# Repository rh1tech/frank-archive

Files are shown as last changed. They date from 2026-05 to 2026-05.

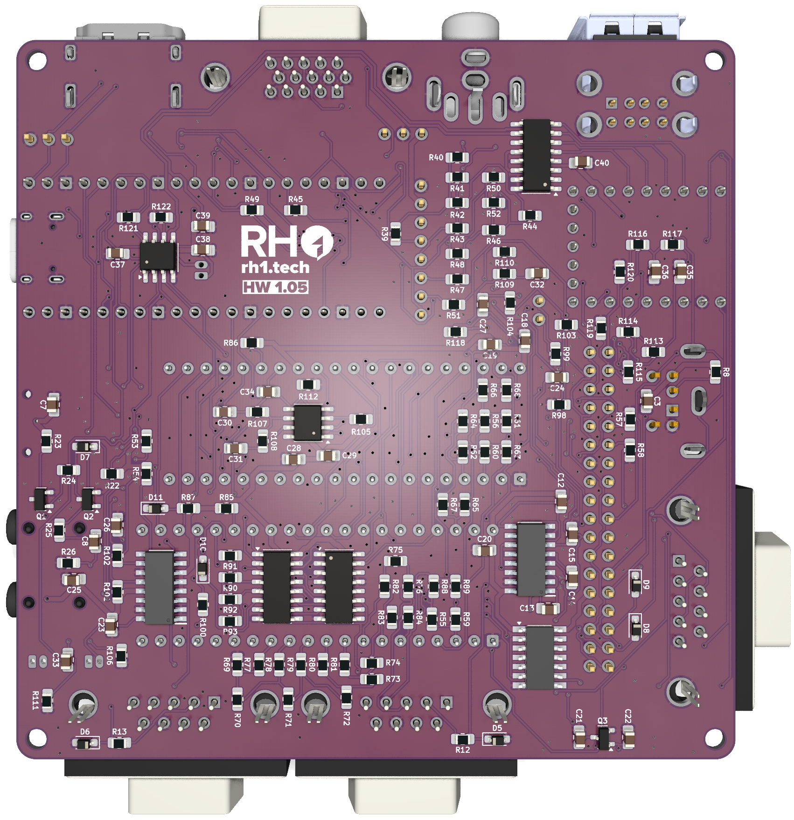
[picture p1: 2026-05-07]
turbofrank_m1p1/docs/back.png

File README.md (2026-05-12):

# FRANK Archive

Official page: **[frank.rh1.tech](https://frank.rh1.tech/)** — hub for all FRANK boards and firmware.

Archive of FRANK board revisions — schematics, layouts, and reference assets for each released and prototyped variant of the FRANK family.

Each subdirectory corresponds to a specific board revision, including the FRANK, MicroFRANK, MiniFRANK, TinyFRANK, TurboFRANK, and related accessory boards (HDMI-to-VGA, USB-to-PS/2).

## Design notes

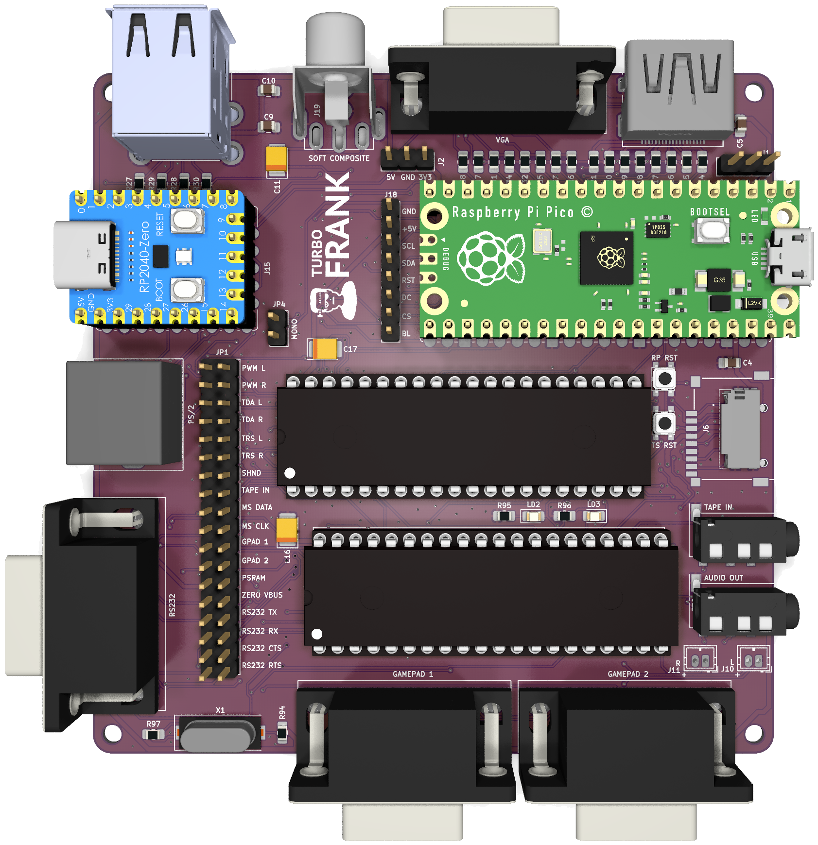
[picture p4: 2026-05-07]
turbofrank_m1p1/docs/front.png

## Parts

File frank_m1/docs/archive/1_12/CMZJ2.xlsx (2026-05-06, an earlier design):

Reference | Value | Qty | Type | AliExpress
AU1 | AUDIO OUT | 1 | PJ-325C | https://www.aliexpress.com/item/1005006710837751.html
AU2 | AUDIO IN | 1 | PJ-325C | https://www.aliexpress.com/item/1005006710837751.html
C1,C2,C3,C6 | 1u | 4 | Polar | https://www.aliexpress.com/item/1005002524973878.html
C4,C7,C8,C14,C5,C13 | 100n | 6 | SMD | https://www.aliexpress.com/item/32964553793.html
C9,C10,C15 | 10u | 3 | 0805 | https://www.aliexpress.com/item/32964553793.html
C11,C12 | 10n | 2 | 0805 | https://www.aliexpress.com/item/32964553793.html
C16 | 220u | 1 | Polar | https://www.aliexpress.com/item/1005002524973878.html
CON1 | Display | 1 | 2.54 | https://www.aliexpress.com/item/1005007039504981.html
CON2 | OUT | 1 | 2.54 | https://www.aliexpress.com/item/1005007039504981.html
CON3 | IN | 1 | 2.54 | https://www.aliexpress.com/item/1005007039504981.html
D1,D2,D3 | 1N4148 | 3 | SOD-323 | https://www.aliexpress.com/item/1005007681952673.html
D4,D5,D6,D7,PWR2 | 3V3 | 5 | SOD-323 | https://www.aliexpress.com/item/32997486634.html
DB1 | RS232 | 1 | DB9 Female | https://www.aliexpress.com/item/4000659356343.html
DB2,DB3 | Joystick | 2 | DB9 Female | https://www.aliexpress.com/item/4000659356343.html
HDMI1 | HDMI | 1 | Female 4 DIP | https://www.aliexpress.com/item/1005005248842433.html
JP1 | JMP RUN | 1 | 2.54 | https://www.aliexpress.com/item/1005007039504981.html
JP2 | Main Jumpers | 1 | 2.54 | https://www.aliexpress.com/item/1005007039504981.html
JP3 | GP18 Jumper | 1 | 2.54 | https://www.aliexpress.com/item/1005007039504981.html
JP4 | GP19 Jumper | 1 | 2.54 | https://www.aliexpress.com/item/1005007039504981.html
JP5 | JMP PSRAM | 1 | 2.54 | https://www.aliexpress.com/item/1005007039504981.html
JP6 | RS232 Jumpers | 1 | 2.54 | https://www.aliexpress.com/item/1005007039504981.html
JP7,JP9,JP10 | RP ZERO +5V Jumper | 3 | 2.54 | https://www.aliexpress.com/item/1005007039504981.html
JP8 | I2S | 1 | 2.54 | https://www.aliexpress.com/item/1005007039504981.html
KB1 | PS/2 | 1 | PS/2 6P | https://www.aliexpress.com/item/4000106131593.html
L1 | LED | 1 | 0805 | https://www.aliexpress.com/item/838002118.html
MAX1 | MAX232CSE+ | 1 | SO 16PIN | https://www.aliexpress.com/item/1005006286473801.html
PSR1 | PSRAM | 1 | SOP8 | https://www.aliexpress.com/item/1005006440914173.html
PWR1 | 5V | 1 | 2.54 | https://www.aliexpress.com/item/1005007039504981.html
Q1,Q2 | BC850 | 2 | SOT-23 | https://www.aliexpress.com/item/33017911878.html
R1,R2,R11,R35,R36,R37,R38,R55 | 1K | 8 | 0805 | https://www.aliexpress.com/item/1005005600798857.html
R3,R4,R5,R6,R7,R8,R9,R10,R40,R41,R42,R43,R44,R45 | 270R | 14 | 0805 | https://www.aliexpress.com/item/1005005600798857.html
R12,R13,R14,R25,R26 | 330R | 5 | 0805 | https://www.aliexpress.com/item/1005005600798857.html
R15,R16,R17,R30,R33 | 1k | 5 | 0805 | https://www.aliexpress.com/item/1005005600798857.html
R18,R19,R20,R21,R27,R28,R29,R34 | 10K | 8 | 0805 | https://www.aliexpress.com/item/1005005600798857.html
R22,R23,R24,R47,R48 | 100R | 5 | 0805 | https://www.aliexpress.com/item/1005005600798857.html
R31,R32 | 2k | 2 | 0805 | https://www.aliexpress.com/item/1005005600798857.html
R39 | 750R | 1 | 0805 | https://www.aliexpress.com/item/1005005600798857.html
R46 | 300R | 1 | 0805 | https://www.aliexpress.com/item/1005005600798857.html
R49,R50,R51,R52,R53 | 150R | 5 | 0805 | https://www.aliexpress.com/item/1005005600798857.html
R54 | 51R | 1 | 0805 | https://www.aliexpress.com/item/1005005600798857.html
R56,R57 | 5.1K | 2 | 0805 | https://www.aliexpress.com/item/1005005600798857.html
RP1 | RP2040 Pico | 1 | Pico | https://www.aliexpress.com/item/1005006055009344.html
RP2 | RP 2040 Zero | 1 | Zero | https://www.aliexpress.com/item/1005006354505058.html
SC1 | VIDEO (Soft Composite) | 1 | RCA-103 | https://www.aliexpress.com/item/1005006152724809.html
SD1 | Micro SD | 1 | Push-Push | https://www.aliexpress.com/item/1005004214252441.html
SW1 | SW_Push_Dual | 1 | 3 x 3 x 1.5 mm | https://www.aliexpress.com/item/1005001629293584.html
TDA1 | TDA1387T | 1 | SOP-8 | https://www.aliexpress.com/item/32995595000.html
UART1 | UART | 1 | 2.54 | https://www.aliexpress.com/item/1005007039504981.html
USB1 | USB Type C | 1 | 16 Pin SMT | https://www.aliexpress.com/item/1005005500797563.html
VGA1 | VGA | 1 | DB15 Female 90 Degree | https://www.aliexpress.com/item/32842951548.html

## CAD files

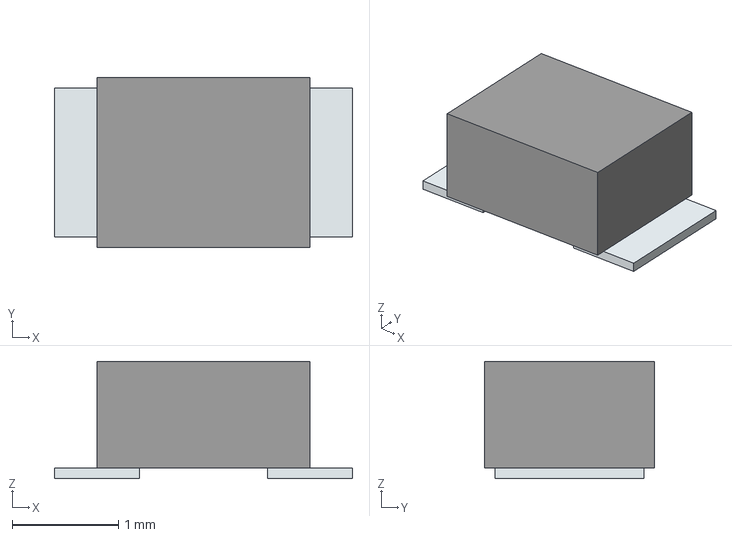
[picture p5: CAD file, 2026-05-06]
microfrank_rm1p2u/3D/ASMPH-0806-3R3M-T.stp
2.80 x 1.60 x 1.10 mm
Pins

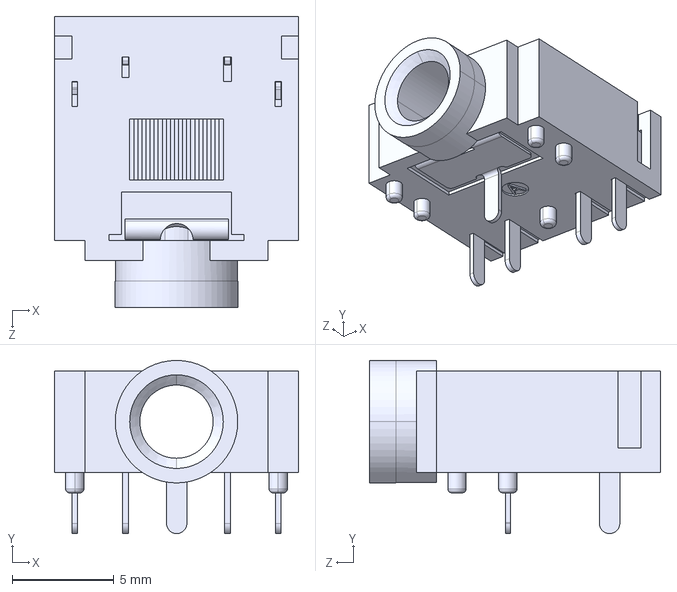
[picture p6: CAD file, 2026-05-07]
frank_fastbeta_m1/3d/SJ1-3525N.stp
12.0 x 8.51 x 14.3 mm

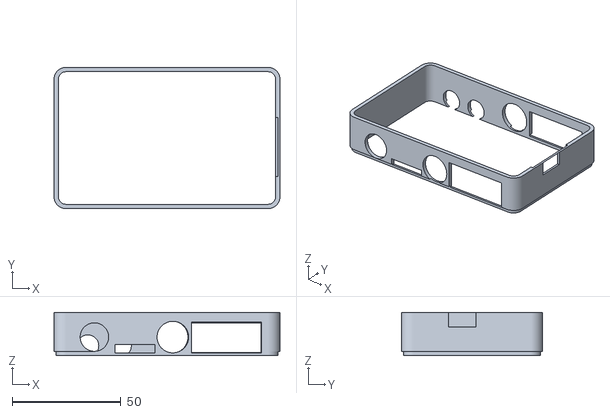
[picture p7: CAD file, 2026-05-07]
frank_fastbeta_m1/case/1_04/body_vga.stl
104.0 x 65.0 x 20.0

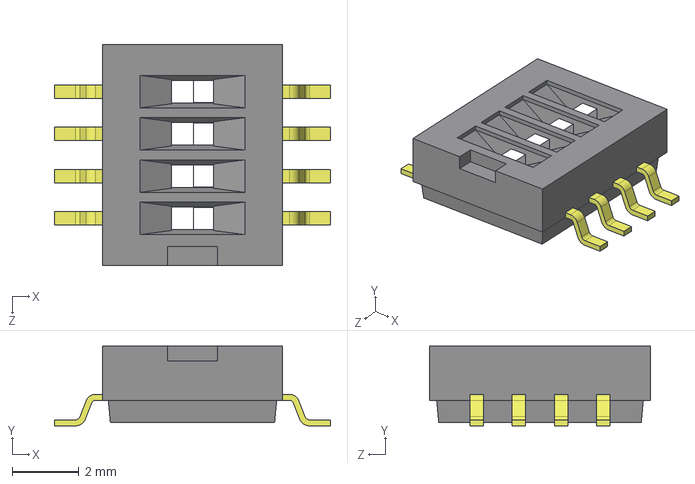
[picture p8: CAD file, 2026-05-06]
frank_m1/3d/DS05-127-2-04BK-SMT-TR.step
8.30 x 2.40 x 6.65 mm

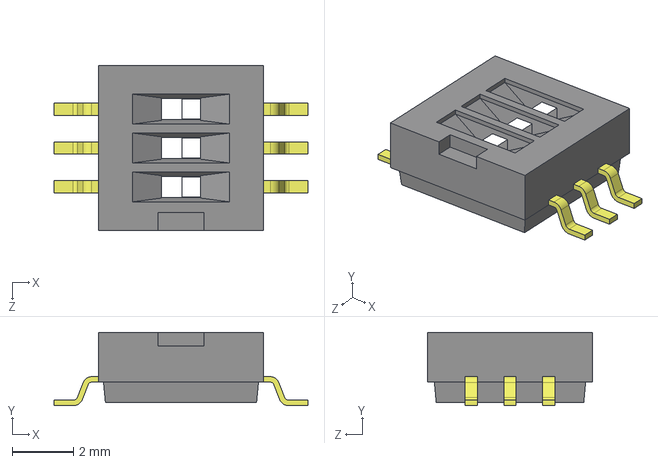
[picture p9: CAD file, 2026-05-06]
frank_rm1p2/3D/DS05-127-2-03BK-SMT-TR.step
8.30 x 2.40 x 5.38 mm

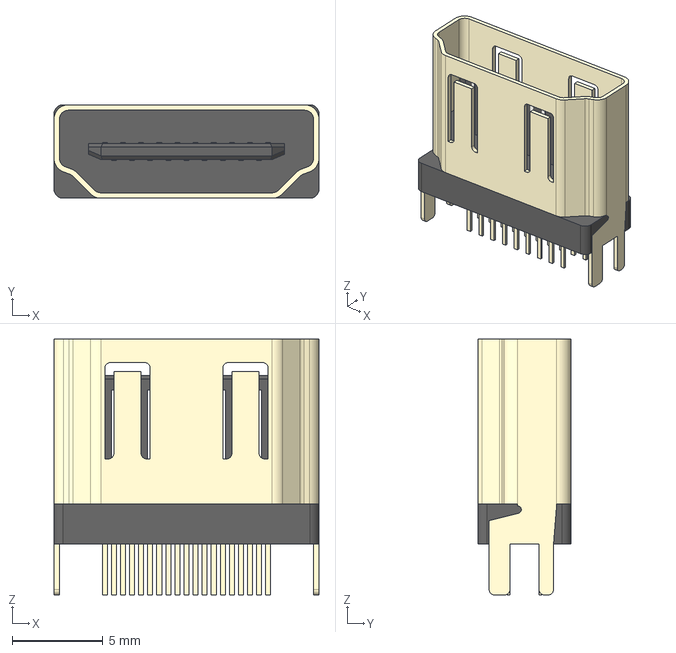
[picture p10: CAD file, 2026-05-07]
hdmi2vga/3d/HDMI_vertical.stp
14.6 x 5.15 x 14.1 mm

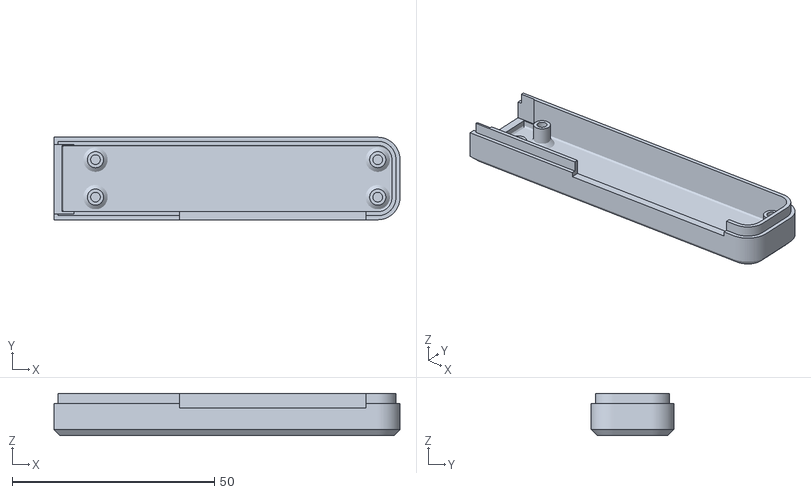
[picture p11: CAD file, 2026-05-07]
hdmi2vga/case/2_02/bottom.stl
85.5 x 20.4 x 10.5

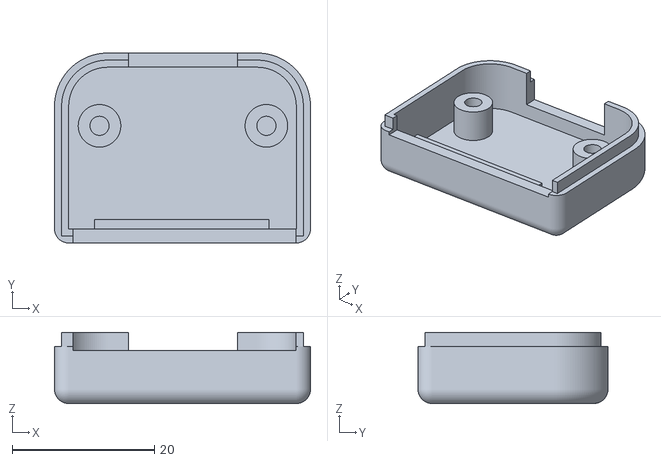
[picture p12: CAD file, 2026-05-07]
hdmi2vga/case/2_03/bottom.stl
36.0 x 26.8 x 10.0

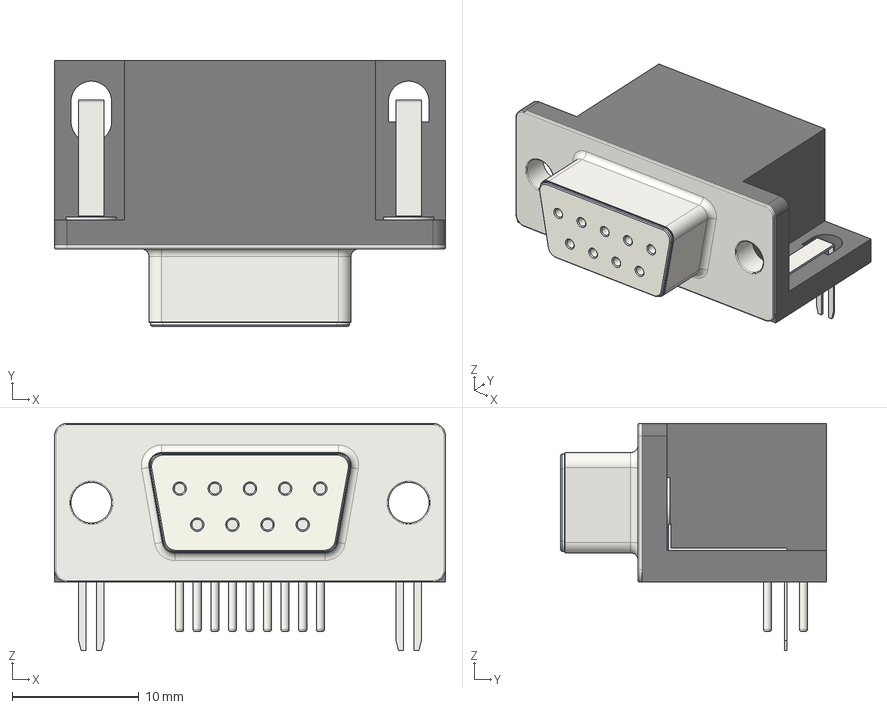
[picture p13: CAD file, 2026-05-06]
microfrank_rm1p2/3D/DSUB-9_Female_Horizontal_P2.77x2.84mm_EdgePinOffset9.90mm_Housed_MountingHolesOffset11.32mm.step
30.8 x 20.9 x 17.9 mm

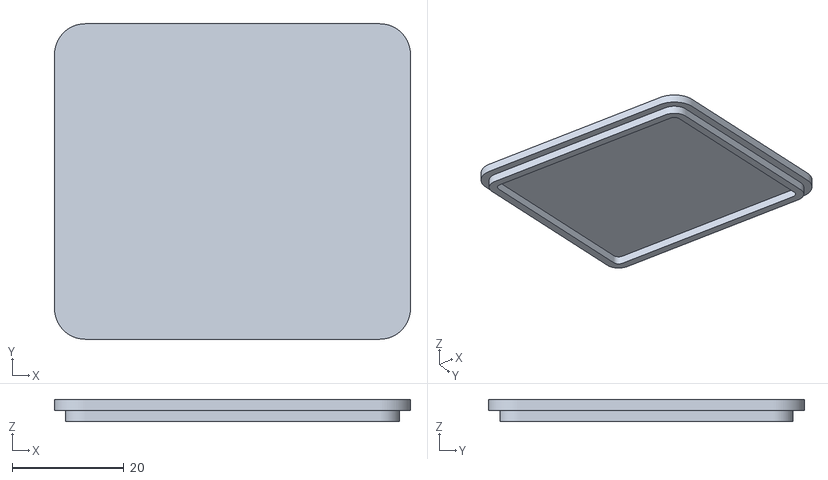
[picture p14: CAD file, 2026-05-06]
microfrank_rm1p2/CASE/1_00/cover.stl
63.8 x 56.5 x 4.00

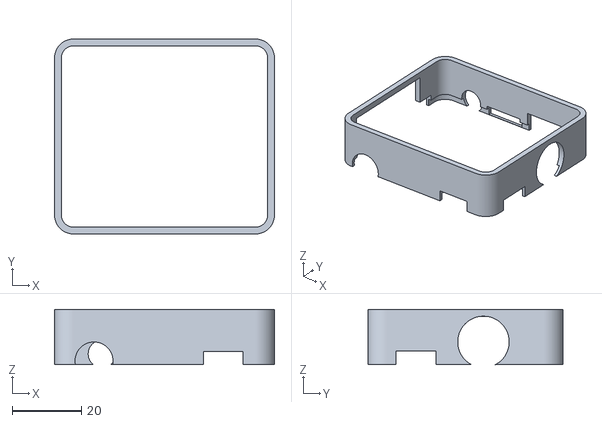
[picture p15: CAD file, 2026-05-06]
microfrank_rm1p2/CASE/1_01/middle.stl
63.8 x 56.5 x 16.0

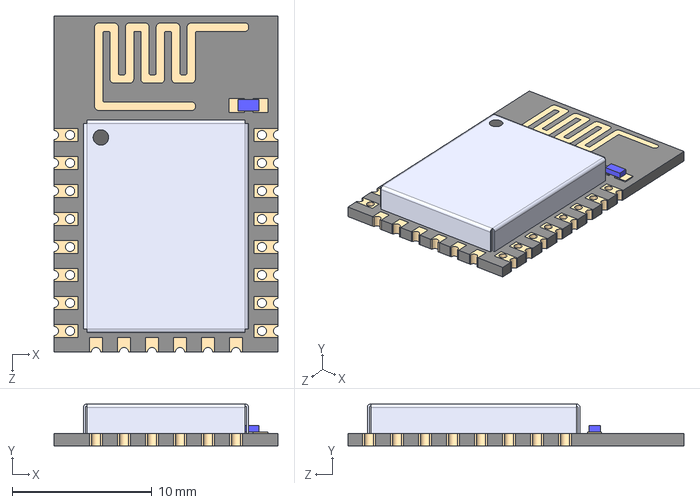
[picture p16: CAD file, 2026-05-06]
minifrank_m1/3D/ESP8266-12E_ESP-12E.step
16.0 x 3.00 x 24.0 mm

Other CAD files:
frank_fastbeta_m1/3d/1x20 Male Pin Header.STEP
frank_fastbeta_m1/3d/CD4069UBE.stp
frank_fastbeta_m1/3d/CUI_DEVICES_RCJ-013.step
frank_fastbeta_m1/3d/DC-005-5A-2.0.step
frank_fastbeta_m1/3d/FHU-1x20.step
frank_fastbeta_m1/3d/MP1584EN-LF-Z.stp
frank_fastbeta_m1/3d/Micro_SD_Card_and_Holder.stp
frank_fastbeta_m1/3d/Mini-DIN-6P.step
frank_fastbeta_m1/case/1_04/body_hdmi.stl
frank_fastbeta_m1/case/1_04/bottom_hdmi.stl
frank_fastbeta_m1/case/1_04/bottom_vga.stl
frank_fastbeta_m1/case/1_04/cover.stl
frank_m1/3d/CD4069UBM.stp
frank_m1/3d/CDRH104RNP-150NC.stp
frank_m1/3d/DS05-127-2-06BK-SMT-TR.stp
frank_rm1p2/3D/DS04-254-2-01BK-SMT.step
frank_rm1p2/3D/DS05-127-2-06BK-SMT-TR.stp
frank_rm1p2/3D/DSUB-15-HD_Male_Horizontal_P2.29x1.98mm_EdgePinOffset3.03mm_Housed_MountingHolesOffset4.94mm.step
frank_rm1p2/3D/SJ1-3535NG.stp
frank_rm1p2/3D/SO-8_5.3x6.2mm_P1.27mm.step
frank_rm1p2/3D/Ts-1233_1.5.stp
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

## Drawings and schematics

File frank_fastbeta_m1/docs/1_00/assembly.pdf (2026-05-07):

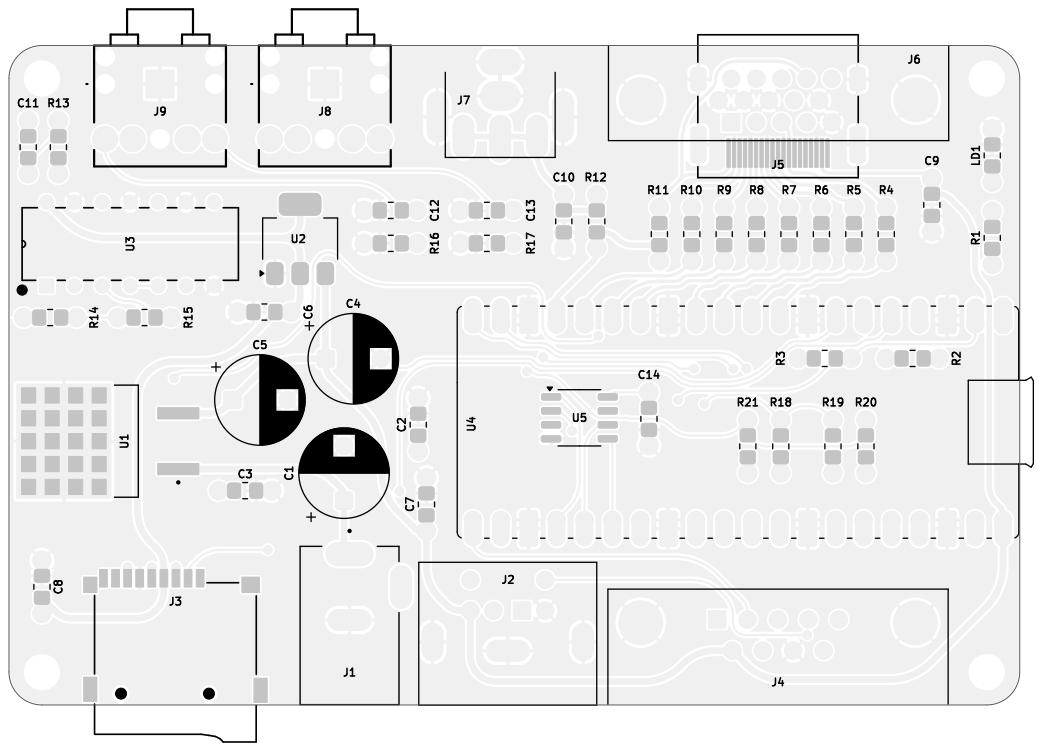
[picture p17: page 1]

Id: /1 Title: FRANK Fastbeta PWT

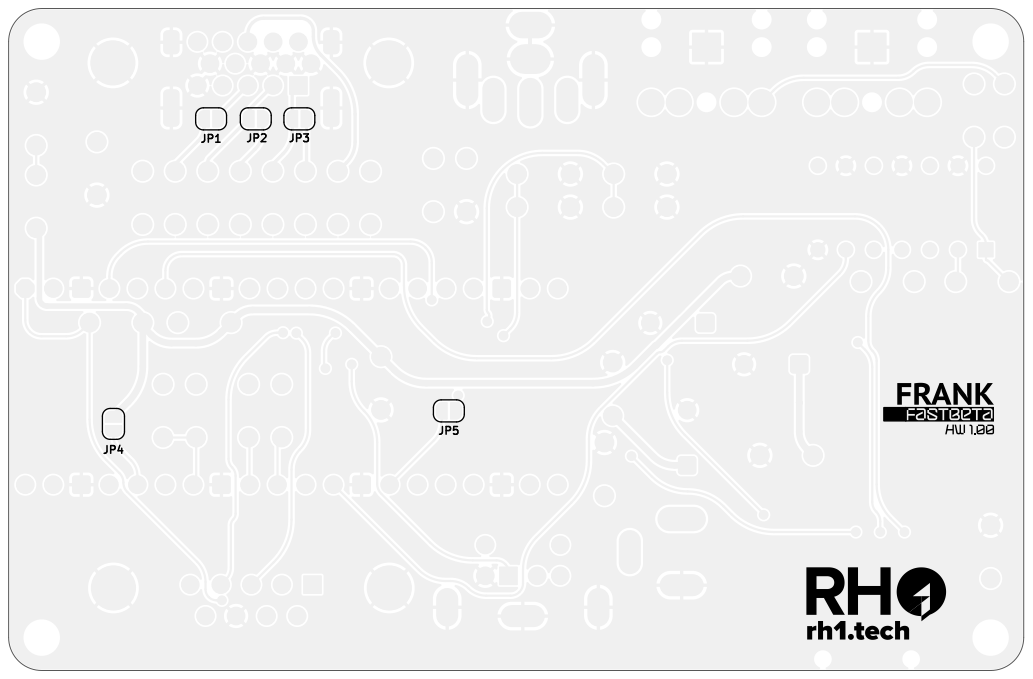
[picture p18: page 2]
D Date: 2025-09-10 KiCad; E.D.A. 9.0.4 Size: A4; Rev: 1.00; File: fastbeta_pwt.kicad_pcb Sheet: Black; And; White; BOT Mikhail; Matveev; https://github.com/xtremespb/frank Black; BOT -; Page 2/4

Id: /1 Title: FRANK Fastbeta PWT

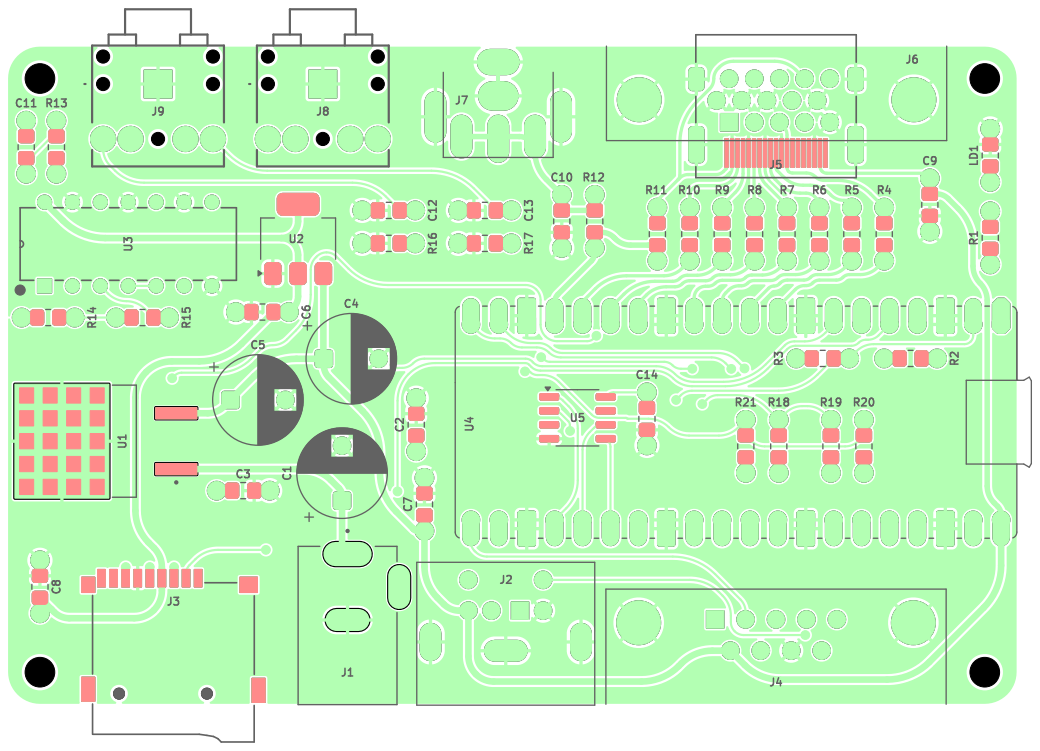
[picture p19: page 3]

Id: /1 Title: FRANK Fastbeta PWT

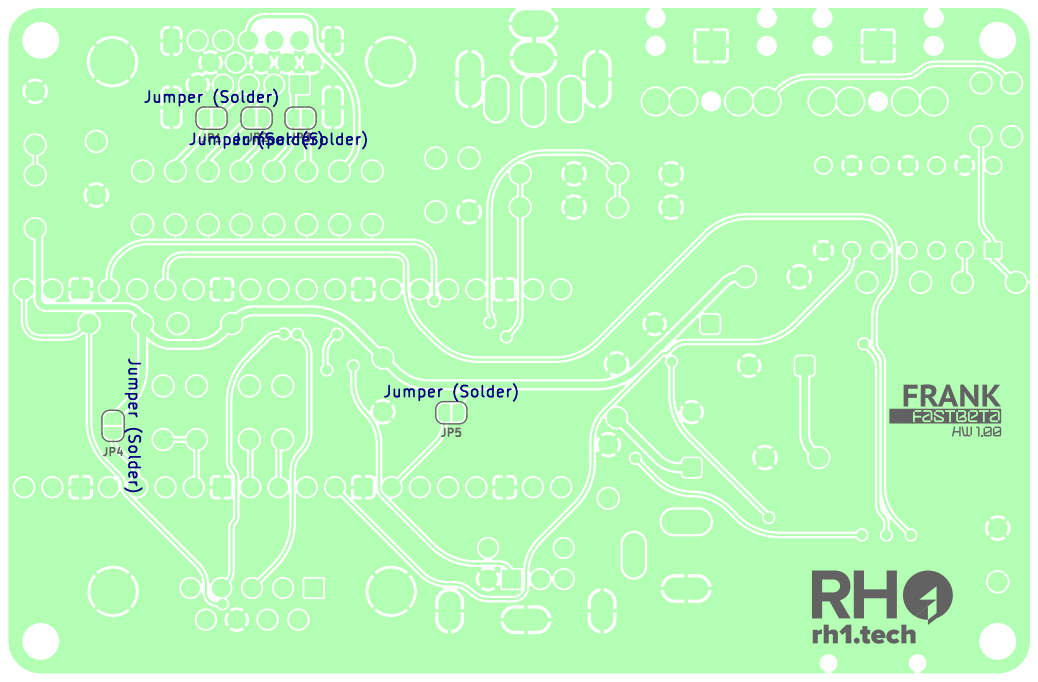
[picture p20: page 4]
D Date: 2025-09-10 KiCad; E.D.A. 9.0.4 Size: A4; Rev: 1.00; File: fastbeta_pwt.kicad_pcb Sheet: Colored; BOT Mikhail; Matveev; https://github.com/xtremespb/frank Colored; BOT -; Page 4/4 Jumper (Solder); Jumper (Solder) Jumper (Solder) Jumper (Solder); Jumper (Solder)

Id: /1 Title: FRANK Fastbeta PWT

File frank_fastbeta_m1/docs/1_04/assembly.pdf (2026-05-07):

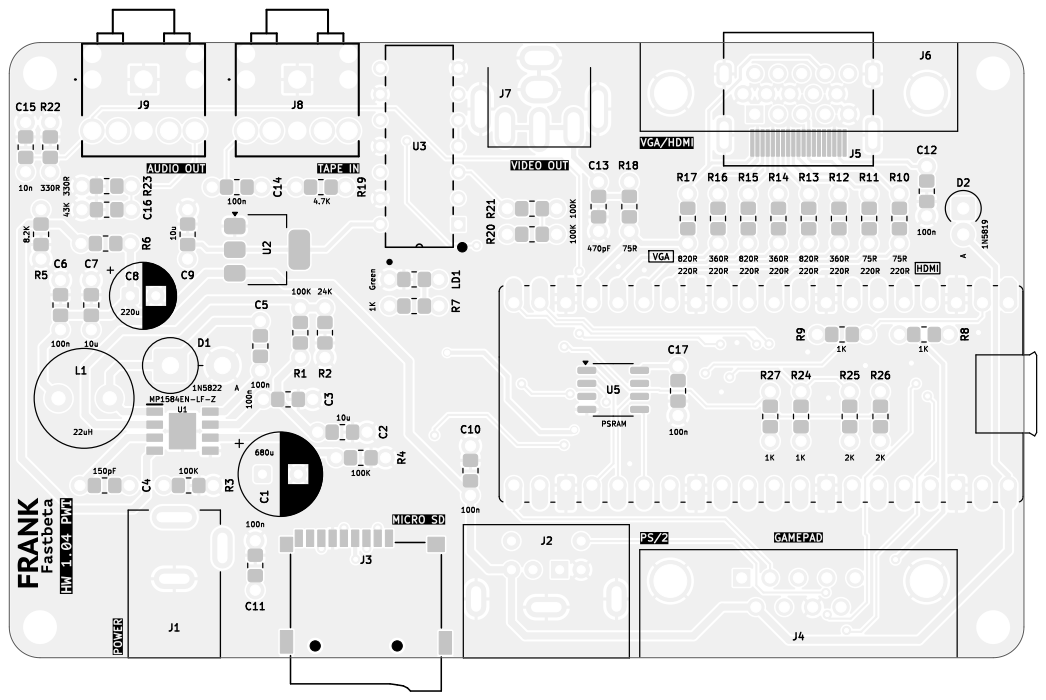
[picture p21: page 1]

https://github.com/xtremespb/frank Black And White TOP - Page 1/4

File: fastbeta_pwt.kicad_pcb Sheet: Black And White TOP Mikhail Matveev

Id: /1 Title: FRANK Fastbeta PWT

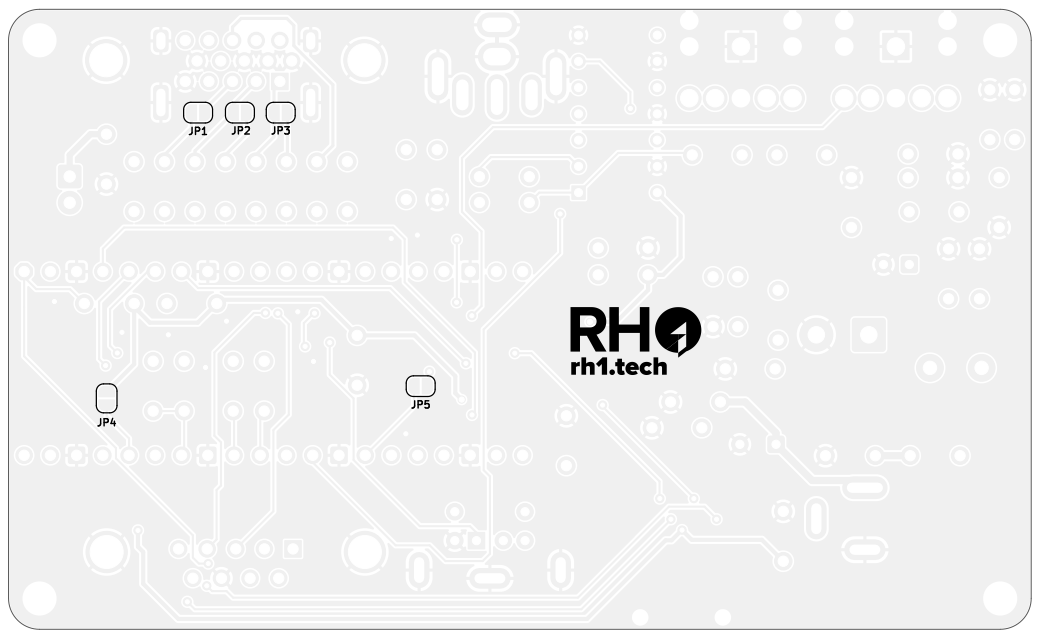
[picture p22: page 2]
D Date: 2025-10-23 KiCad; E.D.A. 9.0.5 Size: A4; Rev: 1.04; File: fastbeta_pwt.kicad_pcb Sheet: Black; And; White; BOT Mikhail; Matveev; https://github.com/xtremespb/frank Black; BOT -; Page 2/4

Id: /1 Title: FRANK Fastbeta PWT

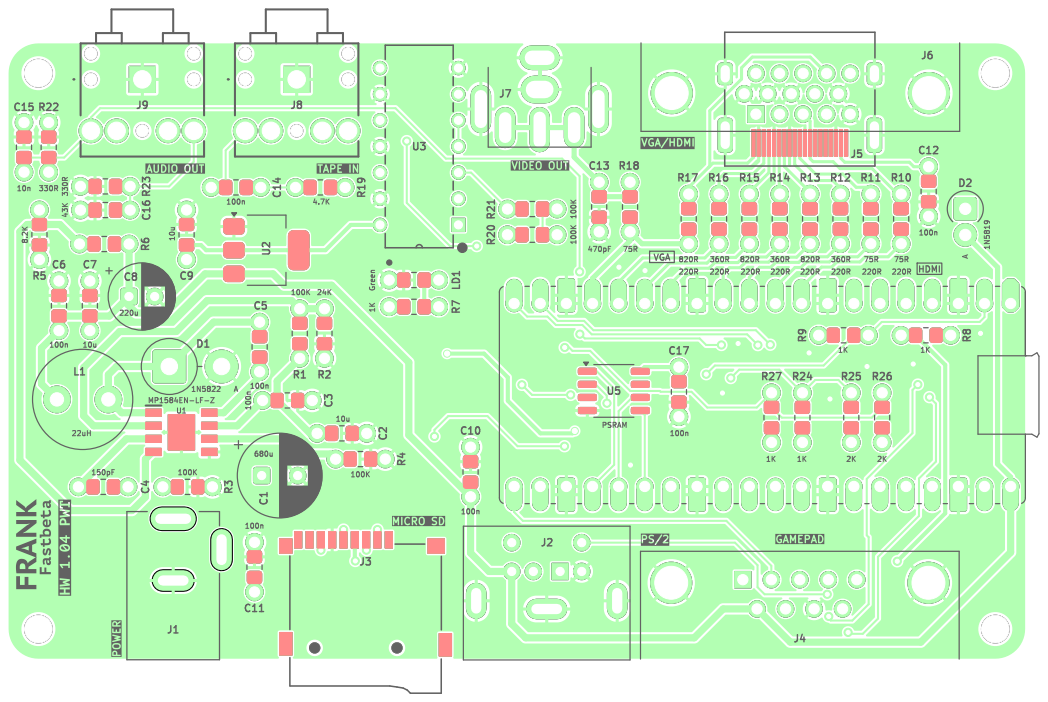
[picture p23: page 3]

Id: /1 Title: FRANK Fastbeta PWT

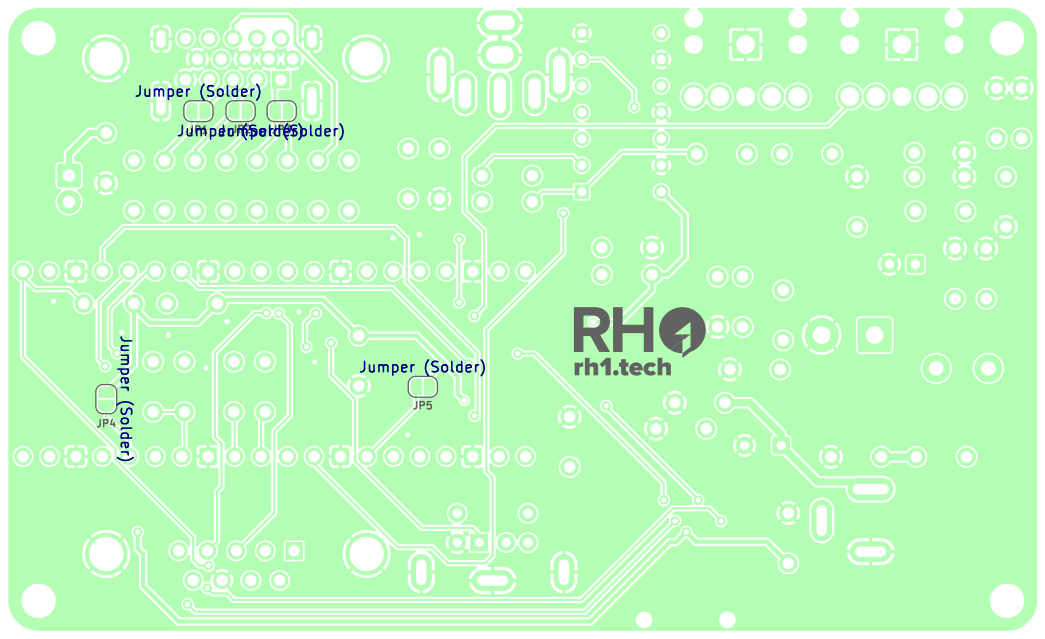
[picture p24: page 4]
D Date: 2025-10-23 KiCad; E.D.A. 9.0.5 Size: A4; Rev: 1.04; File: fastbeta_pwt.kicad_pcb Sheet: Colored; BOT Mikhail; Matveev; https://github.com/xtremespb/frank Colored; BOT -; Page 4/4 Jumper (Solder); Jumper (Solder) Jumper (Solder) Jumper; (Solder); Jumper (Solder)

Id: /1 Title: FRANK Fastbeta PWT

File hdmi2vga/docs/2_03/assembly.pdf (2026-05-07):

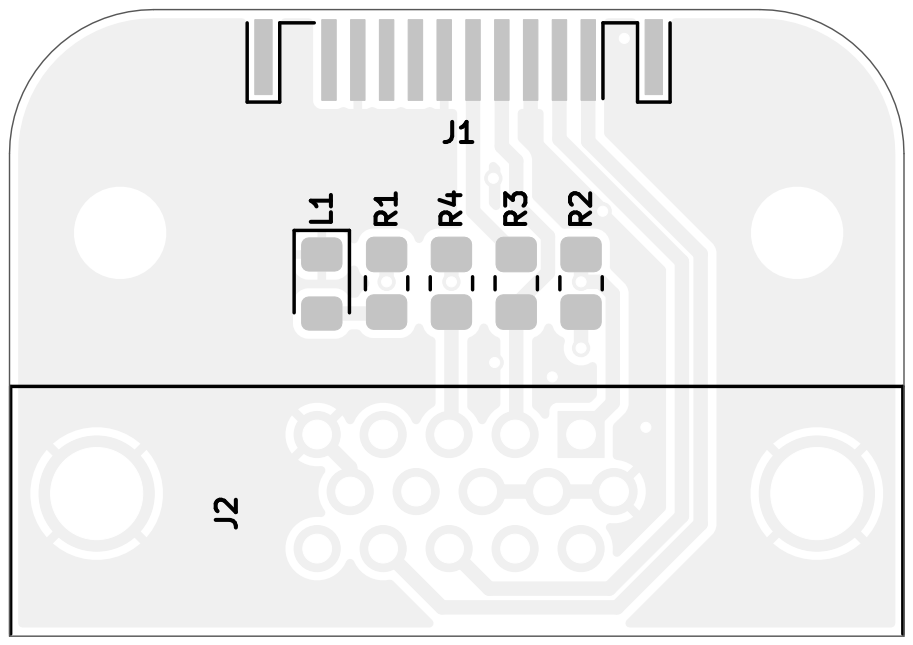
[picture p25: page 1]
D Date: 2025-05-07 KiCad; E.D.A. 9.0.0 Size: A4; Rev: 2.03; Id: /1 Title: HDMI2VGA; File: hdmi2vga.kicad_pcb Sheet: Black; And; White; TOP Mikhail; Matveev; https://github.com/xtremespb/frank Black; TOP -; Page

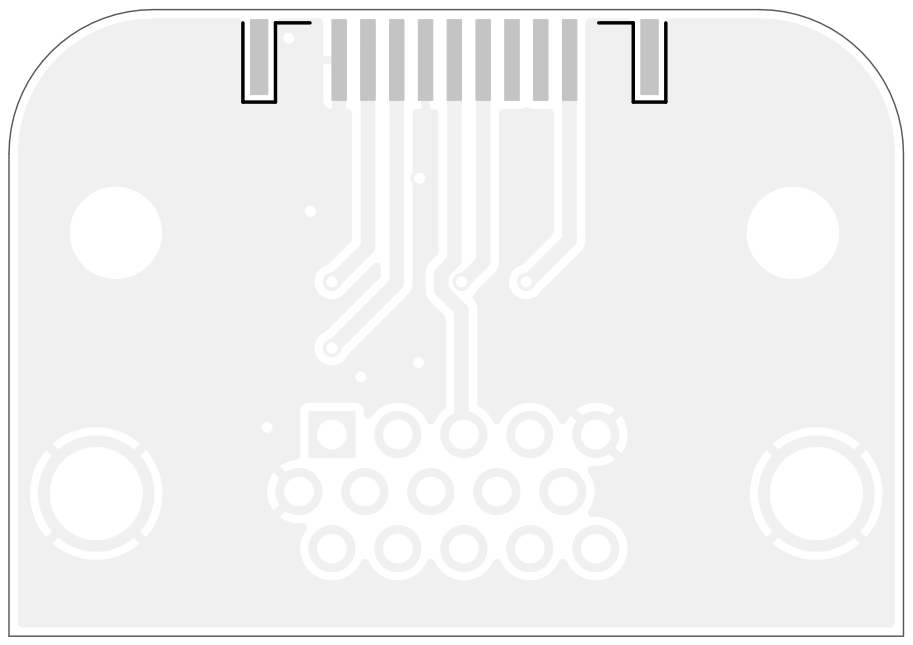
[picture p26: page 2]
D Date: 2025-05-07 KiCad; E.D.A. 9.0.0 Size: A4; Rev: 2.03; Id: /1 Title: HDMI2VGA; File: hdmi2vga.kicad_pcb Sheet: Black; And; White; BOT Mikhail; Matveev; https://github.com/xtremespb/frank Black; BOT -; Page 2/4

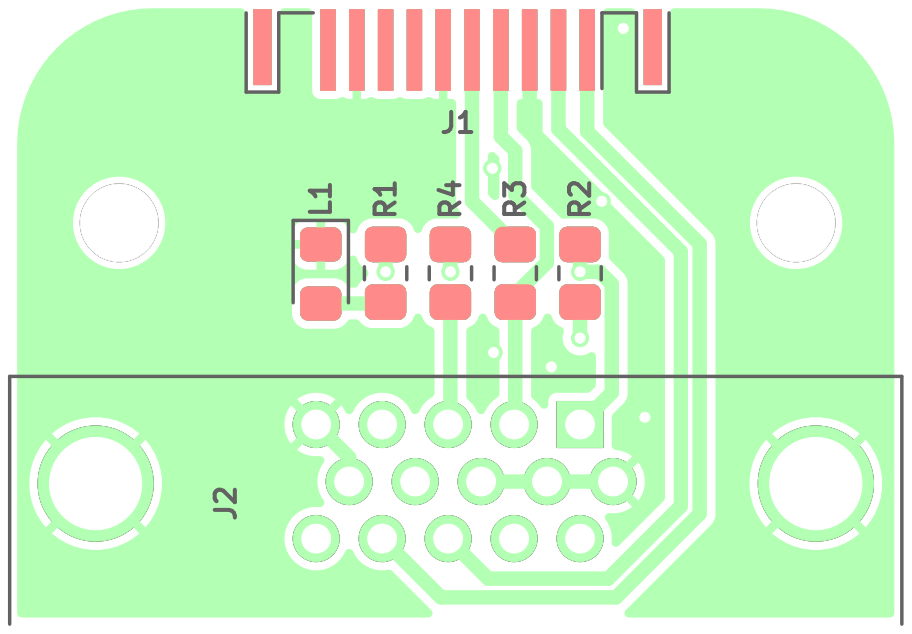
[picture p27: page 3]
D Date: 2025-05-07 KiCad; E.D.A. 9.0.0 Size: A4; Rev: 2.03; Id: /1 Title: HDMI2VGA; File: hdmi2vga.kicad_pcb Sheet: Colored; TOP Mikhail; Matveev; https://github.com/xtremespb/frank Colored; TOP -; Page 3/4 L1

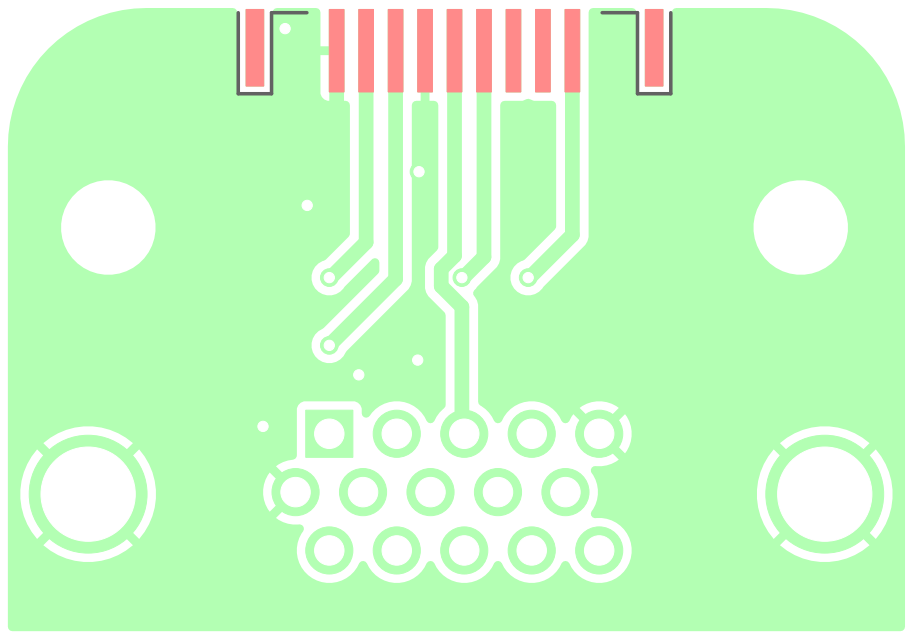
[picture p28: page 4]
D Date: 2025-05-07 KiCad; E.D.A. 9.0.0 Size: A4; Rev: 2.03; Id: /1 Title: HDMI2VGA; File: hdmi2vga.kicad_pcb Sheet: Colored; BOT Mikhail; Matveev; https://github.com/xtremespb/frank Colored; BOT -; Page 4/4

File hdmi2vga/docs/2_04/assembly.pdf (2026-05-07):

D Date: 2025-07-22 KiCad; E.D.A. 9.0.0 Size: A4; Rev: 2.04; Id: /1 Title: HDMI2VGA; File: hdmi2vga.kicad_pcb Sheet: Black; And; White; TOP Mikhail; Matveev; https://github.com/xtremespb/frank Black; TOP -; Page

D Date: 2025-07-22 KiCad; E.D.A. 9.0.0 Size: A4; Rev: 2.04; Id: /1 Title: HDMI2VGA; File: hdmi2vga.kicad_pcb Sheet: Black; And; White; BOT Mikhail; Matveev; https://github.com/xtremespb/frank Black; BOT -; Page 2/4

D Date: 2025-07-22 KiCad; E.D.A. 9.0.0 Size: A4; Rev: 2.04; Id: /1 Title: HDMI2VGA; File: hdmi2vga.kicad_pcb Sheet: Colored; TOP Mikhail; Matveev; https://github.com/xtremespb/frank Colored; TOP -; Page 3/4 J2

D Date: 2025-07-22 KiCad; E.D.A. 9.0.0 Size: A4; Rev: 2.04; Id: /1 Title: HDMI2VGA; File: hdmi2vga.kicad_pcb Sheet: Colored; BOT Mikhail; Matveev; https://github.com/xtremespb/frank Colored; BOT -; Page 4/4

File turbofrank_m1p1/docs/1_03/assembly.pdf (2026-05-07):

TAPE | BL Gamepad 1 Reset | SDA

# R43 CON¹


R105 Pin Header 1x03 CON² D-SUB 9 Male GP2

File: turbofrank.kicad_pcb Sheet: Black And White TOP Mikhail Matveev

1 | 2 | 3 | 4 | 5 | 6

A


File: turbofrank.kicad_pcb Sheet: Black And White BOT Mikhail Matveev

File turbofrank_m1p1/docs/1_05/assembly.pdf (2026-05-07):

1 | 2 | 3 | 4 | 5 | 6

A


https://github.com/xtremespb/frank Black And White TOP - Page 1/4

File: turbofrank.kicad_pcb Sheet: Black And White TOP Mikhail Matveev

R116 R68 R79 R22 C26 | R104 C30R86 | U10 | R42 R39 C34R107 1 | 2 | 3 | 4 | 5 | 6 1 | 2 | 3 | 4 | 5 | 6 ABCD | ABCD Date: 2025-04-05 KiCad E.D.A. 9.0.0 Size: A4 | Rev: 1.05


https://github.com/xtremespb/frank Black And White BOT - Page 2/4

File: turbofrank.kicad_pcb Sheet: Black And White BOT Mikhail Matveev

1 | 2 | 3 | 4 | 5 | 6

A


R116 R68 R79 R22 C26 | R104 C30R86 | U10 | R42 R39 C34R107 1 | 2 | 3 | 4 | 5 | 6 1 | 2 | 3 | 4 | 5 | 6 ABCD | ABCD Date: 2025-04-05 KiCad E.D.A. 9.0.0 Size: A4 | Rev: 1.05
R40 | 300R


https://github.com/xtremespb/frank Colored BOT - Page 4/4

File: turbofrank.kicad_pcb Sheet: Colored BOT Mikhail Matveev

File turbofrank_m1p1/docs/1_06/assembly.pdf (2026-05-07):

1 | 2 | 3 | 4 | 5 | 6

A


https://github.com/xtremespb/frank Black And White TOP - Page 1/4

File: turbofrank.kicad_pcb Sheet: Black And White TOP Mikhail Matveev


https://github.com/xtremespb/frank Black And White BOT - Page 2/4

File: turbofrank.kicad_pcb Sheet: Black And White BOT Mikhail Matveev

1 | 2 | 3 | 4 | 5 | 6

A


LM358 U10 TDA1387T U11 | MW7211A U12 10K
R40 | 300R


https://github.com/xtremespb/frank Colored BOT - Page 4/4 ¹uC23

File: turbofrank.kicad_pcb Sheet: Colored BOT Mikhail Matveev

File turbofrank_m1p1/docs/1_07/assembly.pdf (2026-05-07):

# J10 R²⁰

1 | 2 | 3 | 4 | 5 | 6


File: turbofrank_m1p1.kicad_pcb Sheet: Black And White TOP Mikhail Matveev

R112 R75 R22 C27 | R100 C31R82 | U11 | R42 R39 C35R103 1 | 2 | 3 | 4 | 5 | 6 1 | 2 | 3 | 4 | 5 | 6 ABCD | ABCD Date: 2025-05-01 KiCad E.D.A. 9.0.7 Size: A4 | Rev: 1.07
R40 | 300R


File: turbofrank_m1p1.kicad_pcb Sheet: Black And White BOT Mikhail Matveev

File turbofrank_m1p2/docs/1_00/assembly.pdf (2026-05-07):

R68 | R³⁰ U3 1 | 2 | 3 | 4 | 5 | 6 1 | 2 | 3 | 4 | 5 | 6 ABCD | ABCD Date: 2025-07-25 KiCad E.D.A. 9.0.0 Size: A4 | Rev: 1.00


https://github.com/xtremespb/frank Black And White TOP - Page 1/4

File: turbofrank_rm1p2.kicad_pcb Sheet: Black And White TOP Mikhail Matveev

1 | 2 | 3 | 4 | 5 | 6

A

D Date: 2025-07-25 KiCad; E.D.A. 9.0.0 Size: A4; Rev: 1.00; File: turbofrank_rm1p2.kicad_pcb Sheet: Black; And; White; BOT Mikhail; Matveev; https://github.com/xtremespb/frank Black; BOT -; Page 2/4

Id: /1 Title: TurboFRANK RM1P2

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


1 | 2 | 3 | 4 | 5 | 6

A

D Date: 2025-07-25 KiCad; E.D.A. 9.0.0 Size: A4; Rev: 1.00; File: turbofrank_rm1p2.kicad_pcb Sheet: Colored; BOT Mikhail; Matveev; https://github.com/xtremespb/frank Colored; BOT -; Page 4/4 Mouse (DATA) Mouse (CLK)

Id: /1 Title: TurboFRANK RM1P2

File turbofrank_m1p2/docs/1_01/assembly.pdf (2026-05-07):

C52 C⁴⁹ 1 | 2 | 3 | 4 | 5 | 6 1 | 2 | 3 | 4 | 5 | 6 ABCD | ABCD Date: 2025-08-11 KiCad E.D.A. 9.0.0 Size: A4 | Rev: 1.01


https://github.com/xtremespb/frank Black And White TOP - Page 1/4

File: turbofrank_rm1p2.kicad_pcb Sheet: Black And White TOP Mikhail Matveev

1 | 2 | 3 | 4 | 5 | 6

A

D Date: 2025-08-11 KiCad; E.D.A. 9.0.0 Size: A4; Rev: 1.01; File: turbofrank_rm1p2.kicad_pcb Sheet: Black; And; White; BOT Mikhail; Matveev; https://github.com/xtremespb/frank Black; BOT -; Page 2/4

Id: /1 Title: TurboFRANK RM1P2

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


1 | 2 | 3 | 4 | 5 | 6

A

D Date: 2025-08-11 KiCad; E.D.A. 9.0.0 Size: A4; Rev: 1.01; File: turbofrank_rm1p2.kicad_pcb Sheet: Colored; BOT Mikhail; Matveev; https://github.com/xtremespb/frank Colored; BOT -; Page 4/4 Mouse (CLK) Mouse (DATA)

Id: /1 Title: TurboFRANK RM1P2

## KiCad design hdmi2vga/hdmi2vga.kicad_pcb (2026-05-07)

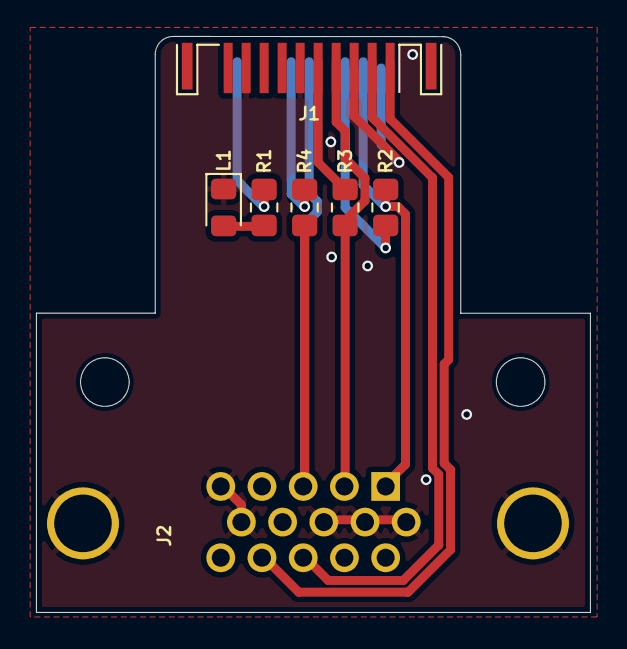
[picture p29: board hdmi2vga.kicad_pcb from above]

Board: 2 copper layers, 30.8 x 32.0 mm, 9 parts (0 on the bottom side), 11 nets.

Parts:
H1, H2: MountingHole; Mounting Hole (2.7mm)
J1: HDMI; HDMI (male)
J2: VGA; D-SUB (15 pin, female)
L1: HDMI LED; LED (0805)
R1: 1K; Resistor (0805)
R2, R3, R4: 820R; Resistor (0805)

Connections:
/CLKN_VGA_B: J1.12 (CLKN), R4.1
/CLKP_VGA_BH: J1.10 (CLKP), J2.3, R4.2
/D0N_VGA_G: J1.9 (D0N), R3.1
/D0P_VGA_GH: J1.7 (D0P), J2.2, R3.2
/D1N_VGA_R: J1.6 (D1N), R2.1
/D1P_VGA_RH: J1.4 (D1P), J2.1, R2.2
/D2N_VGA_HS: J1.3 (D2N), J2.13
/D2P_VGA_VS: J1.1 (D2P), J2.14
GND: J1.2 (G_D2), J1.5 (G_D1), J1.8 (G_D0), J1.11 (G_CLK), J1.17 (G_DDC/CEC), J2.0, J2.5, J2.6, J2.7, J2.8, J2.10, L1.1 (K)
unnamed: J1.18 (+5V), R1.1
unnamed: L1.2 (A), R1.2

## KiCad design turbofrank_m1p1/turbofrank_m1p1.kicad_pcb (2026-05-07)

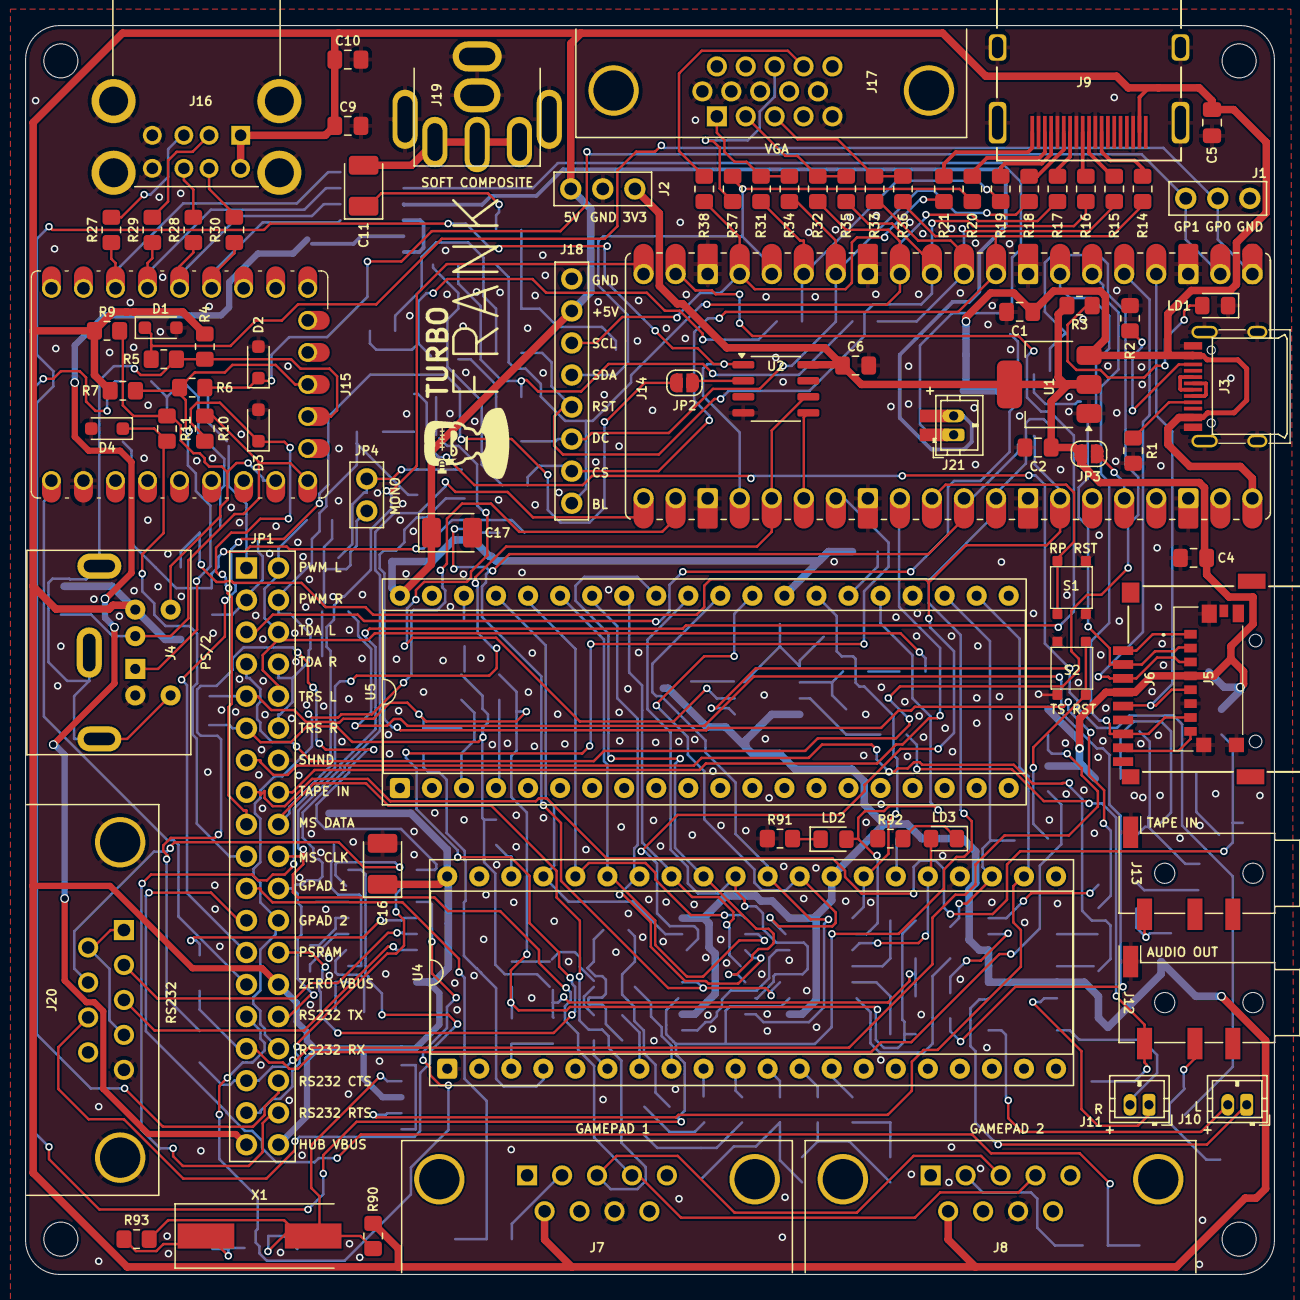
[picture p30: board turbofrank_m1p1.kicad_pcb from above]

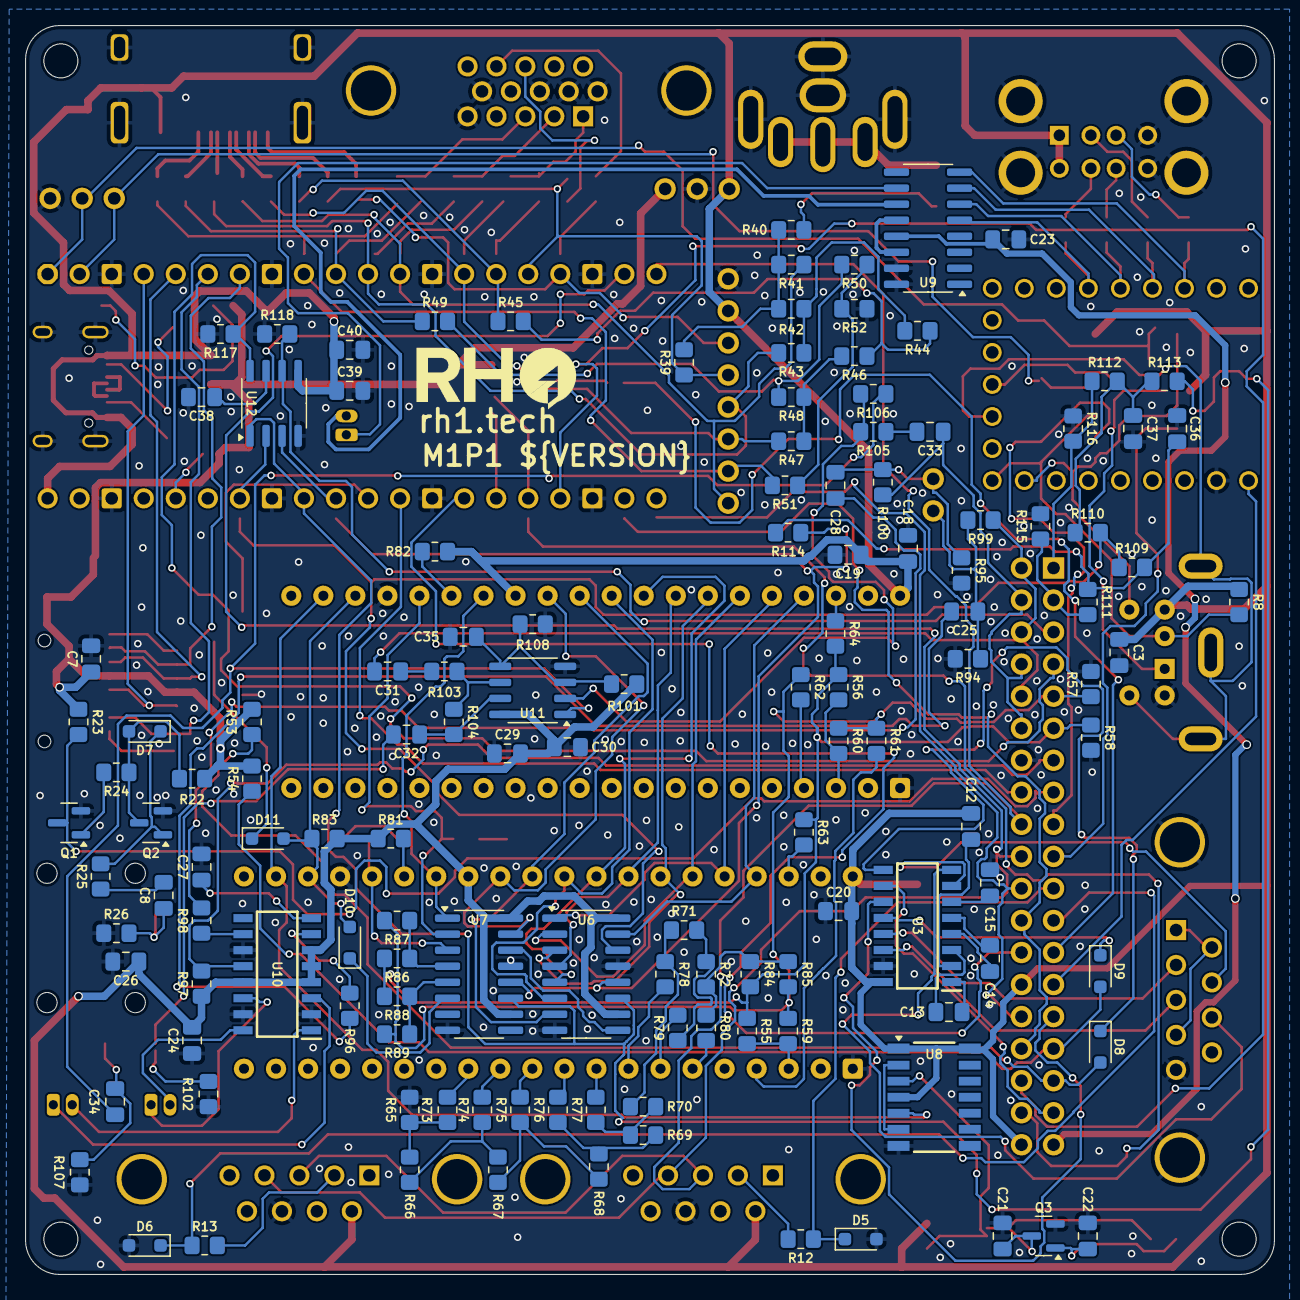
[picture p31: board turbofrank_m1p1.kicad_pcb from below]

Board: 2 copper layers, 99.0 x 99.0 mm, 219 parts (132 on the bottom side), 187 nets.

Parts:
C1, C2, C9, C10, C29, C31, C32, C33, C34, C35, C38, C39: 10u; Capacitor (0805)
C3, C4, C5, C6, C7, C8, C18, C19, C20, C27, C30, C40: 100n; Capacitor (0805)
C11: 220u; Capacitor (3528, tantalum, polar)
C12, C13, C14, C15, C24, C25, C28: 1u; Capacitor (0805)
C16, C17: 100u; Capacitor (3528, tantalum, polar)
C21, C22: 22p; Capacitor (0805)
C23: 4.7u; Capacitor (0805)
C26: 47u; Capacitor (0805)
C36, C37: 47n; Capacitor (0805)
D1, D2, D3, D4, D5, D6: 3V3; Diode (SOD-323)
D7, D8, D9, D10, D11: 1N4148; Diode (SOD-323)
H1, H2, H3, H4: Hole 2.7mm; Mounting Hole (2.7mm)
J1: UART; Pin Header (1x03)
J2: PWR; Pin Header (1x03)
J3: USB4215; USB Type C
J4: MDC-036; MiniDIN (6 Pin, female)
J5: 0475710001; MicroSD (SMD, short)
J6: 104031-0811; MicroSD (SMD, long)
J7, J8, J20: D-SUB 9 Male; D-SUB (9 pin, male, top mount)
J9: DC3RX19JA2; HDMI (female)
J10: PAM L; Connector Female ZH 1.50mm (2 pins)
J11: PAM R; Connector Female ZH 1.50mm (2 pins)
J12, J13: PJ-320D; Jack (3.5mm, PJ-320D)
J14: Rasberry Pi Pico; Raspberry Pi Pico
J15: RP2040-Zero; Raspberry Pi Zero
J16: SS-52100-004; USB Type A (stacked)
J17: D-SUB 15 Female; D-SUB (15 pin, female)
J18: Pin Header 1x08; Pin Header (1x08)
J19: RCA-103; RCA
J21: USB HUB Data; Connector Female ZH 1.50mm (2 pins + tracks)
JP1: Main Jumper Set; Pin Header (2x19)
JP2, JP3: Jumper (Solder); Jumper (solder)
JP4: Mono; Pin Header (1x02)
LD1: Green; LED (0805)
LD2, LD3: Orange; LED (0805)
Q1, Q2, Q3: BC850; SOT-23
R1, R2: 5.1K; Resistor (0805)
R3, R4, R7, R8, R9, R12, R13, R23, R34, R35, R36, R53, R54, R66, R67, R68, R69, R70, R71, R72, R81, R82, R90, R91, R92, R113, R114: 1K; Resistor (0805)
R5, R6, R10, R11, R26, R37, R38: 100R; Resistor (0805)
R14, R15, R16, R17, R18, R19, R20, R21, R41, R43, R45, R47, R49, R51: 270R; Resistor (0805)
R22, R24, R25, R83, R84, R85, R86, R87, R88, R89, R96, R97, R98, R99, R100, R101, R103, R105, R108, R111, R112: 10K; Resistor (0805)
R27, R28, R29, R30: 22R; Resistor (0805)
R31, R32, R33: 330R; Resistor (0805)
R39: 750R; Resistor (0805)
R40: 51R; Resistor (0805)
R42, R44, R46, R48, R50: 150R; Resistor (0805)
R52: 300R; Resistor (0805)
R55, R56, R61, R62, R65, R73, R74, R75, R76, R77, R78, R79, R80, R94, R95, R109, R110, R115, R116: 2K; Resistor (0805)
R57, R58: 120R; Resistor (0805)
R59, R60, R63, R64: 4.7K; Resistor (0805)
R93: 100K; Resistor (0805)
R102, R107: 20K; Resistor (0805)
R104, R106: 47K; Resistor (0805)
R117, R118: 470R; Resistor (0805)
S1: TS-1233; Button (SMD, 3x3mm, 1-1)
S2: KLS7-TS3302; Button (SMD, 3x3mm, 1-1)
U1: NCP1117 3.3; SOT-223
U2: ESP-PSRAM32; SO-8
U3: MAX232CSE+; SOIC127P600X175-16N
U4, U5: JFC95101; DIP-40 (Socket)
U6, U7: 74HC595; SOP-16
U8: 74HC74; 74HCT74D
U9: MW7211A; SOP-16
U10: PAM8403D; SOIC127P600X175-16N
U11: LM358; SO-8
U12: TDA1387T; SO-8
X1: 3.58 MHz; Crystal (HC49-S)

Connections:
+3V3: C2.1, C4.2, C6.1, C7.1, J2.1, J5.P4 (VDD), J6.4 (VDD), JP3.2 (B), R3.2, R22.1, R23.1, R53.2, R54.2, U1.2 (VO), U2.8 (VCC)
/AMP_IN_L: C31.1, JP1.2, JP1.6, JP1.10, R99.1
/AMP_IN_R: C33.1, JP1.4, JP1.8, JP1.12, R100.1
/Audio Out/AMP_OUTL: C32.2, J12.T, R102.2
/Audio Out/AMP_OUTR: C34.2, J12.R, R107.2
/Audio Out/AMP_PAM_OUTL_M: J10.2, U10.3 (-OUTL)
/Audio Out/AMP_PAM_OUTL_P: J10.1, U10.1 (+OUT_L)
/Audio Out/AMP_PAM_OUTR_M: J11.2, U10.14 (-OUT_R)
/Audio Out/AMP_PAM_OUTR_P: J11.1, U10.16 (+OUT_R)
/Audio Out/Amplifier/ MONO_L: C25.1, JP4.1, R94.1, R99.2
/Audio Out/Amplifier/MONO_R: C28.1, JP4.2, R95.1, R100.2
/Audio Out/TS/A1: R62.2, U5.4 (B)
/Audio Out/TS/A2: R61.2, U4.4 (B)
/Audio Out/TS/B1: R56.2, R60.2, U5.3 (A)
/Audio Out/TS/B2: R55.2, R59.2, U4.3 (A)
/Audio Out/TS/BEEP: R86.2, R87.2, U7.4 (QE)
/Audio Out/TS/C1: R64.2, U5.38 (C)
/Audio Out/TS/C2: R63.2, U4.38 (C)
/Audio Out/TS/CLK_1.75M: U4.22 (CLOCK), U5.22 (CLOCK), U8.5 (Q)
/Audio Out/TS/COVOX_OUT: R72.2, R80.1, R84.2, R85.2
/Audio Out/TS/DA0: U4.37 (DA0), U5.37 (DA0), U6.15 (QA)
/Audio Out/TS/DA1: U4.36 (DA1), U5.36 (DA1), U6.1 (QB)
/Audio Out/TS/DA2: U4.35 (DA2), U5.35 (DA2), U6.2 (QC)
/Audio Out/TS/DA3: U4.34 (DA3), U5.34 (DA3), U6.3 (QD)
/Audio Out/TS/DA4: U4.33 (DA4), U5.33 (DA4), U6.4 (QE)
/Audio Out/TS/DA5: U4.32 (DA5), U5.32 (DA5), U6.5 (QF)
/Audio Out/TS/DA6: U4.31 (DA6), U5.31 (DA6), U6.6 (QG)
/Audio Out/TS/DA7: U4.30 (DA7), U5.30 (DA7), U6.7 (QH)
/Audio Out/TS/DAC0: R73.2, U4.13 (IOB0)
/Audio Out/TS/DAC1: R74.2, U4.12 (IOB1)
/Audio Out/TS/DAC2: R75.2, U4.11 (IOB2)
/Audio Out/TS/DAC3: R76.2, U4.10 (IOB3)
/Audio Out/TS/DAC4: R77.2, U4.9 (IOB4)
/Audio Out/TS/DAC5: R78.2, U4.8 (IOB5)
/Audio Out/TS/DAC6: R79.2, U4.7 (IOB6)
/Audio Out/TS/DAC7: R80.2, U4.6 (IOB7)
/Audio Out/TS/SAVE: R88.2, R89.2, U7.5 (QF)
/Audio Out/TS/YM_BC1: U4.29 (BC1), U5.29 (BC1), U7.15 (QA)
/Audio Out/TS/YM_BDIR: U4.27 (BDIR), U5.27 (BDIR), U7.1 (QB)
/Audio Out/TS/YM_CS1: LD2.2 (A), U5.25 (A8), U7.2 (QC)
/Audio Out/TS/YM_CS2: LD3.2 (A), U4.25 (A8), U7.3 (QD)
/Audio Out/TS/YM_RST: D10.2 (A), D11.2 (A), R83.1, U4.23 (~RESET), U5.23 (~RESET)
/Audio Out/TS/YM_SEL1: R82.2, U5.26 (~SEL)
/Audio Out/TS/YM_SEL2: R81.2, U4.26 (~SEL)
/Composite/CVBS: C11.2, J19.1
/GP1_DATA: D5.1 (K), JP1.21, R12.1
/GP2_DATA: D6.1 (K), JP1.23, R13.1
/GPIO0: D1.1 (K), J1.2, J14.1 (GPIO0), R5.2
/GPIO1: D2.1 (K), J1.3, J14.2 (GPIO1), R6.2
/GPIO2: J5.P5 (CLK), J6.5 (CLK), J14.4 (GPIO2)
/GPIO3: J5.P3 (CMD), J6.3 (CMD), J14.5 (GPIO3)
/GPIO4: J5.P7 (DAT0), J6.7 (DAT0), J14.6 (GPIO4)
/GPIO5: J5.P2 (CD/DAT3), J6.2 (DAT3/CD), J14.7 (GPIO5)
/GPIO6: J14.9 (GPIO6), J18.7, R14.2, R36.1, R51.1
/GPIO7: J14.10 (GPIO7), R15.2, R33.1, R49.1
/GPIO8: J14.11 (GPIO8), J18.5, R16.2, R35.1, R43.1
/GPIO9: J14.12 (GPIO9), J18.8, R17.2, R32.1, R41.1
/GPIO10: J14.14 (GPIO10), J18.6, R18.2, R34.1, R47.1
/GPIO11: J14.15 (GPIO11), R19.2, R31.1, R45.1
/GPIO12: J14.16 (GPIO12), J18.4, R20.2, R37.2, R39.1
/GPIO13: J14.17 (GPIO13), J18.3, R21.2, R38.2
/GPIO14: J7.4, J8.4, J14.19 (GPIO14), JP1.20
/GPIO15: J7.3, J8.3, J14.20 (GPIO15), JP1.18
/GPIO16: J14.21 (GPIO16), JP1.22, JP1.30
/GPIO17: J14.22 (GPIO17), JP1.24, JP1.32
/GPIO18: J14.24 (GPIO18), JP1.34, U2.1 (~CE)
/GPIO19: J14.25 (GPIO19), JP1.36, U2.6 (SCLK)
/GPIO20: J14.26 (GPIO20), U2.5 (SI/SIO)
/GPIO21: J14.27 (GPIO21), JP1.26
/GPIO22: J14.29 (GPIO22), JP1.16
/GPIO26: J14.31 (GPIO26_ADC0), R114.2, U6.12 (RCLK), U7.12 (RCLK), U12.3 (DATA)
/GPIO27: J14.32 (GPIO27_ADC1), R113.2, U6.11 (SRCLK), U7.11 (SRCLK), U12.1 (SCLK)
/GPIO28: J14.34 (GPIO28_ADC2), R109.1, R110.1, U6.14 (SER), U12.2 (LRCK)
/KB_CLK: J4.5, J15.13 (12), R4.2, R5.1
/KB_DATA: J4.1, J15.12 (11), R6.1, R7.2
/LOAD_IN_D: JP1.15, Q1.3 (C), R23.2
/MS_CLK: J4.6, J15.16 (15), R9.2, R11.1
/MS_CLK_3V: D4.1 (K), JP1.19, R11.2
/MS_DATA: J4.2, J15.15 (14), R8.2, R10.1
/MS_DATA_3V: D3.1 (K), JP1.17, R10.2
/Micro SD/DAT1: J5.P8 (DAT1), J6.8 (DAT1)
/Micro SD/DAT2: J5.P1 (DAT2), J6.1 (DAT2)
/PSR_SOSIO: JP1.25, JP2.2 (B)
/PWM_OUT_L: JP1.1, R112.2, R116.1
/PWM_OUT_R: JP1.3, R111.2, R115.1
/Power/D+: J3.6 (DP1), J3.8 (DP2)
/Power/D-: J3.5 (DN2), J3.7 (DN1)
/RS232/C1+: C13.2, U3.1 (C1+)
/RS232/C1-: C13.1, U3.3 (C1-)
/RS232/C2+: C14.2, U3.4 (C2+)
/RS232/C2-: C14.1, U3.5 (C2-)
/RS232/CTS_IN: J20.7, U3.7 (T2OUT)
/RS232/CTS_MAX: D8.1 (K), U3.9 (R2OUT)
/RS232/RTS_IN: J20.8, U3.8 (R2IN)
/RS232/RX_IN: J20.3, U3.14 (T1OUT)
/RS232/RX_MAX: D9.1 (K), U3.12 (R1OUT)
/RS232/TX_IN: J20.2, U3.13 (R1IN)
/RS232/V+: C12.1, U3.2 (V+)
/RS232/V-: C15.1, U3.6 (V-)
/RS232_CTS: D8.2 (A), JP1.33, R53.1
/RS232_RTS: JP1.35, U3.10 (T2IN)
/RS232_RX: D9.2 (A), JP1.31, R54.1
/RS232_TX: JP1.29, U3.11 (T1IN)
/RUN: J14.30 (RUN), S1.1
/SHND: JP1.13, R97.2, U10.12 (SHND)
/TDA_L: JP1.5, R118.2, U12.6 (A_LEFT)
/TDA_R: JP1.7, R117.1, U12.8 (A_RIGHT)
/TS_L: JP1.9, R57.1, R59.1, R60.1, R61.1, R62.1, R85.1, R87.1, R89.1
/TS_R: JP1.11, R55.1, R56.1, R58.1, R63.1, R64.1, R84.1, R86.1, R88.1
/USB Hub/DM_IN: J21.2, U9.10 (DMU)
/USB Hub/DP_IN: J21.1, U9.11 (DPU)
/USBH_VBUS: C23.1, JP1.37, U9.13 (VDD5)
/USB_D1M: J15.4 (3), R29.1, U9.7 (DM3)
/USB_D1P: J15.3 (2), R27.1, U9.8 (DP3)
/USB_D2M: J15.6 (5), R30.1, U9.5 (DM2)
/USB_D2P: J15.5 (4), R28.1, U9.6 (DP2)
/ZERO_VBUS: J15.23 (5V), JP1.27
GND: C1.2, C2.2, C3.2, C4.1, C5.2, C6.2, C7.2, C9.2, C10.2, C15.2, C16.2, C17.2, C18.2, C19.2, C20.2, C21.1, C22.1, C23.2, C24.2, C26.2, C27.2, C29.1, C30.1, C35.1, C36.2, C37.2, C38.2, C39.2, C40.2, D1.2 (A), D2.2 (A), D3.2 (A), D4.2 (A), D5.2 (A), D6.2 (A), J1.1, J2.2, J3.1 (GND), J3.12 (GND), J3.13 (SHIELD), J4.3, J5.G1 (GND_1), J5.G2 (GND_2), J5.G3 (GND_3), J5.P6 (VSS), J6.6 (VSS), J7.8, J8.8, J9.2 (G_D2), J9.5 (G_D1), J9.8 (G_D0), J9.11 (G_CLK), J9.17 (G_DDC/CEC), J9.20 (SHIELD1), J9.21 (SHIELD2), J9.22 (SHIELD3), J9.23 (SHIELD4), J12.S, J13.S, J14.3 (GND), J14.8 (GND), J14.13 (GND), J14.18 (GND), J14.23 (GND), J14.28 (GND), J14.33 (AGND), J14.38 (GND), J15.22 (GND), J16.4 (GND1), J16.8 (GND2), J16.9 (Shield), J17.0, J17.5, J17.6, J17.7, J17.8, J17.10, J18.1, J19.2, J20.5, JP1.14, LD1.1 (K), Q1.2 (E), Q2.2 (E), Q3.2 (E), R1.1, R2.1, R26.2, R52.1, R57.2, R58.2, R65.1, R91.1, R92.1, R94.2, R95.2, R102.1, R107.1, R108.1, R115.2, R116.2, R117.2, R118.1, S1.2, S2.2, U1.1 (GND), U2.4 (VSS), U3.15 (GND), U4.1 (VSS), U4.24 (~A9), U5.1 (VSS), U5.24 (~A9), U6.8 (GND), U6.13 (~OE), U7.8 (GND), U7.13 (~OE), U8.7 (GND), U9.15 (GND), U9.16 (GND), U10.2 (PGND), U10.11 (GND), U10.15 (PGND), U11.4 (V-), U12.4 (AGND)
unnamed: C8.1, J13.T, R26.1
unnamed: C8.2, R25.1
unnamed: C11.1, R40.2
unnamed: C25.2, R96.2
unnamed: C28.2, R98.2
unnamed: C31.2, R103.2
unnamed: C32.1, R104.1, U11.7
unnamed: C33.2, R105.2
unnamed: C34.1, R106.1, U11.1
unnamed: C36.1, R109.2, R111.1, R114.1
unnamed: C37.1, R110.2, R112.1, R113.1
unnamed: D7.2 (A), Q2.3 (C), R22.2, R24.1
unnamed: D7.1 (K), Q2.1 (B), R25.2
unnamed: D10.1 (K), U7.6 (QG)
unnamed: D11.1 (K), S2.1
unnamed: J3.4 (CC1), R1.2
unnamed: J3.10 (CC2), R2.2
unnamed: J7.2, R12.2
unnamed: J8.2, R13.2
unnamed: J9.12 (CLKN), R14.1
unnamed: J9.10 (CLKP), R15.1
unnamed: J9.9 (D0N), R16.1
unnamed: J9.7 (D0P), R17.1
unnamed: J9.6 (D1N), R18.1
unnamed: J9.4 (D1P), R19.1
unnamed: J9.3 (D2N), R20.1
unnamed: J9.1 (D2P), R21.1
unnamed: J14.36 (3V3), JP3.1 (A)
unnamed: J16.3 (D1+), R27.2
unnamed: J16.2 (D1-), R29.2
unnamed: J16.7 (D2+), R28.2
unnamed: J16.6 (D2-), R30.2
unnamed: J17.1, R31.2, R34.2
unnamed: J17.2, R32.2, R35.2
unnamed: J17.3, R33.2, R36.2
unnamed: J17.13, R37.1
unnamed: J17.14, R38.1
unnamed: J20.1, J20.4, J20.6
unnamed: JP2.1 (A), U2.2 (SO/SIO)
unnamed: LD1.2 (A), R3.1
unnamed: LD2.1 (K), R91.2
unnamed: LD3.1 (K), R92.2
unnamed: Q1.1 (B), R24.2
unnamed: C22.2, Q3.1 (B), R93.1, X1.1
unnamed: C21.2, Q3.3 (C), R90.1, R93.2, U8.3 (C), X1.2
unnamed: R39.2, R40.1, R41.2, R42.2
unnamed: R42.1, R43.2, R44.2
unnamed: R44.1, R45.2, R46.2
unnamed: R46.1, R47.2, R48.2
unnamed: R48.1, R49.2, R50.2
unnamed: R50.1, R51.2, R52.2
unnamed: R65.2, R66.1, R73.1
unnamed: R66.2, R67.1, R74.1
unnamed: R67.2, R68.1, R75.1
unnamed: R68.2, R69.1, R76.1
unnamed: R69.2, R70.1, R77.1
unnamed: R70.2, R71.1, R78.1
unnamed: R71.2, R72.1, R79.1
unnamed: U6.9 (QH'), U7.14 (SER)
unnamed: U8.2 (D), U8.6 (~Q)
unnamed: U9.12 (VD33), U9.14 (VD3)
unnamed: R96.1, U10.7 (INL)
unnamed: R98.1, U10.10 (INR)
unnamed: C27.1, U10.8 (VREF)
unnamed: C35.2, R101.1, R108.2, U11.3 (+), U11.5 (+)
unnamed: R105.1, R106.2, U11.2 (-)
unnamed: R103.1, R104.2, U11.6 (-)
unnamed: C38.1, U12.7 (FLT)
VBUS: C1.1, C3.1, C5.1, C9.1, C10.1, C12.2, C16.1, C17.1, C18.1, C19.1, C20.1, C24.1, C26.1, C29.2, C30.2, C39.1, C40.1, J2.3, J3.2 (VBUS), J3.11 (VBUS), J4.4, J7.6, J8.6, J9.18 (+5V), J14.40 (VBUS), J16.1 (VBUS1), J16.5 (VBUS2), J18.2, JP1.28, JP1.38, R4.1, R7.1, R8.1, R9.1, R81.1, R82.1, R83.2, R90.2, R97.1, R101.2, U1.3 (VI), U3.16 (VCC), U4.28 (BC2), U4.40 (VCC), U5.28 (BC2), U5.40 (VCC), U6.10 (~SRCLR), U6.16 (VCC), U7.10 (~SRCLR), U7.16 (VCC), U8.1 (~R), U8.4 (~S), U8.14 (VCC), U10.4 (PVDD), U10.5 (MUTE), U10.6 (VDD), U10.13 (PVDD), U11.8 (V+), U12.5 (VA)

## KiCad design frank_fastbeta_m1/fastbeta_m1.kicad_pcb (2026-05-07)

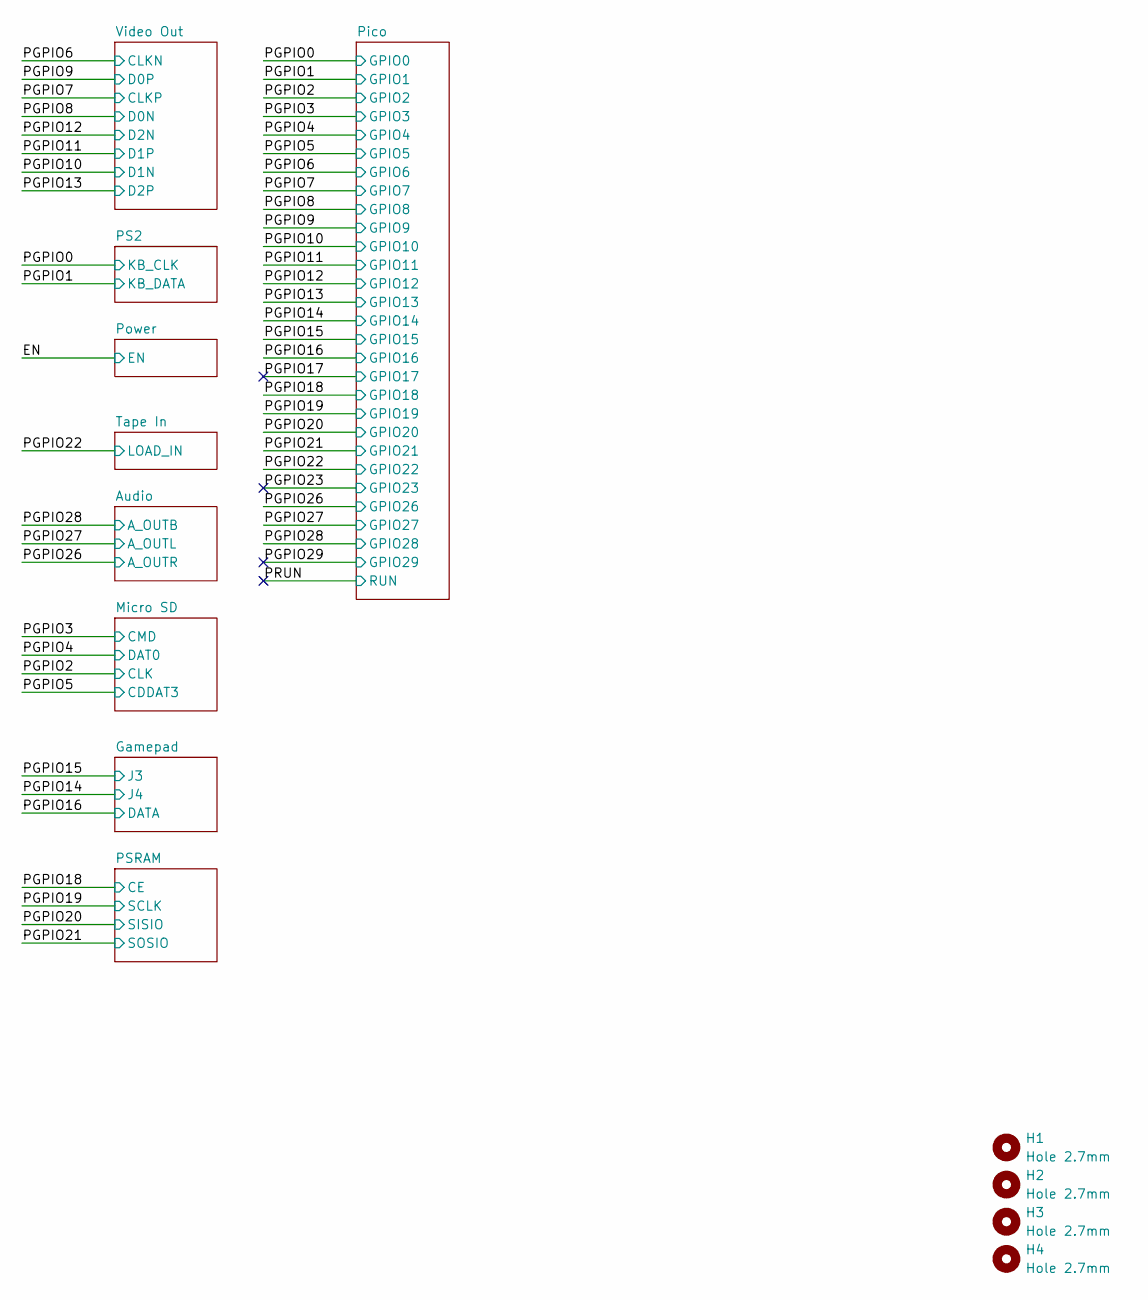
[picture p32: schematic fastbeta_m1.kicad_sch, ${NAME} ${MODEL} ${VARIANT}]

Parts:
H1, H2, H3, H4: Hole 2.7mm; Mounting Hole (2.7mm)

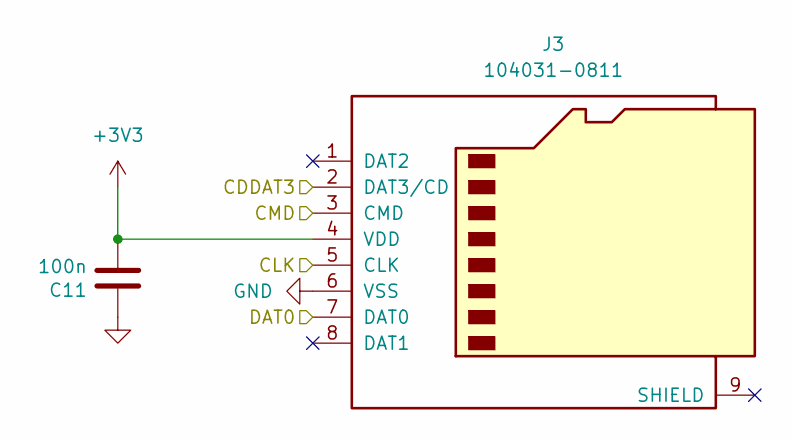
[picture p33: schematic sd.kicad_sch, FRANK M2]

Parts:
C11: 100n; Combined 0805 CR
J3: 104031-0811; MicroSD (SMD, long)

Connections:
+3V3: C11.2, J3.4 (VDD); also elsewhere on the board
/PGPIO2: J3.5 (CLK); also elsewhere on the board
/PGPIO3: J3.3 (CMD); also elsewhere on the board
/PGPIO4: J3.7 (DAT0); also elsewhere on the board
/PGPIO5: J3.2 (DAT3/CD); also elsewhere on the board
GND: C11.1, J3.6 (VSS); also elsewhere on the board

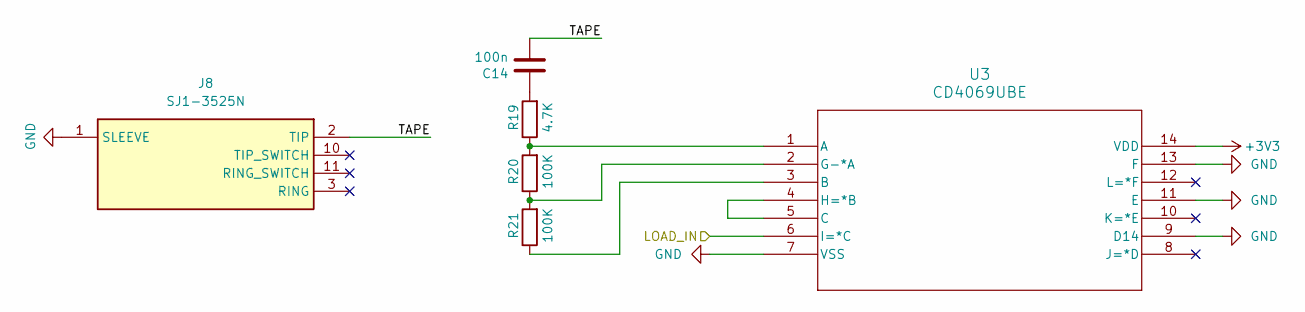
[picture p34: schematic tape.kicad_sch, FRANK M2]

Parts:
C14: 100n; Combined 0805 CR
J8: SJ1-3525N; SJ13525N; Mouser Part Number 490-SJ1-3525N
R19: 4.7K; Combined 0805 RE
R20, R21: 100K; Combined 0805 RE
U3: CD4069UBE

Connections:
+3V3: U3.14 (VDD); also elsewhere on the board
/PGPIO22: U3.6 (I=*C); also elsewhere on the board
/Tape In/TAPE: C14.2, J8.2 (TIP)
GND: J8.1 (SLEEVE), U3.7 (VSS), U3.9 (D14), U3.11 (E), U3.13 (F); also elsewhere on the board
unnamed: C14.1, R19.2
unnamed: R19.1, R20.2, U3.1 (A)
unnamed: R21.1, U3.3 (B)
unnamed: U3.4 (H=*B), U3.5 (C)
unnamed: R20.1, R21.2, U3.2 (G-*A)

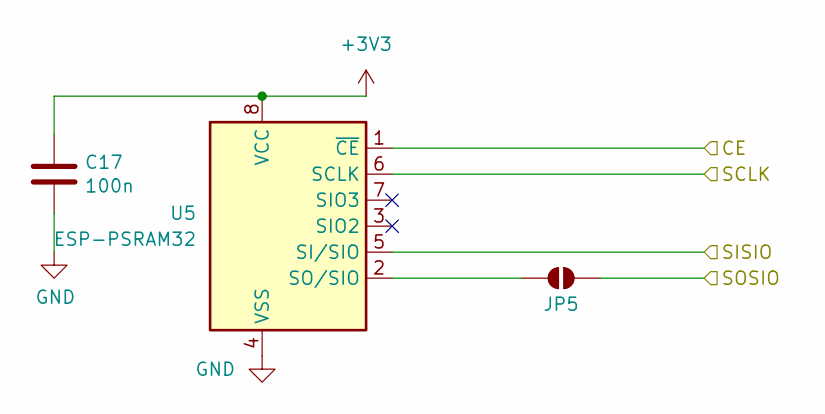
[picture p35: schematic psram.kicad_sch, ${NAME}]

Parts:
C17: 100n; Combined 0805 CR
JP5: Jumper (Solder); Jumper (solder)
U5: ESP-PSRAM32; SO-8

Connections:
+3V3: C17.1, U5.8 (VCC); also elsewhere on the board
/PGPIO18: U5.1 (~CE); also elsewhere on the board
/PGPIO19: U5.6 (SCLK); also elsewhere on the board
/PGPIO20: U5.5 (SI/SIO); also elsewhere on the board
/PGPIO21: JP5.2 (B); also elsewhere on the board
GND: C17.2, U5.4 (VSS); also elsewhere on the board
unnamed: JP5.1 (A), U5.2 (SO/SIO)

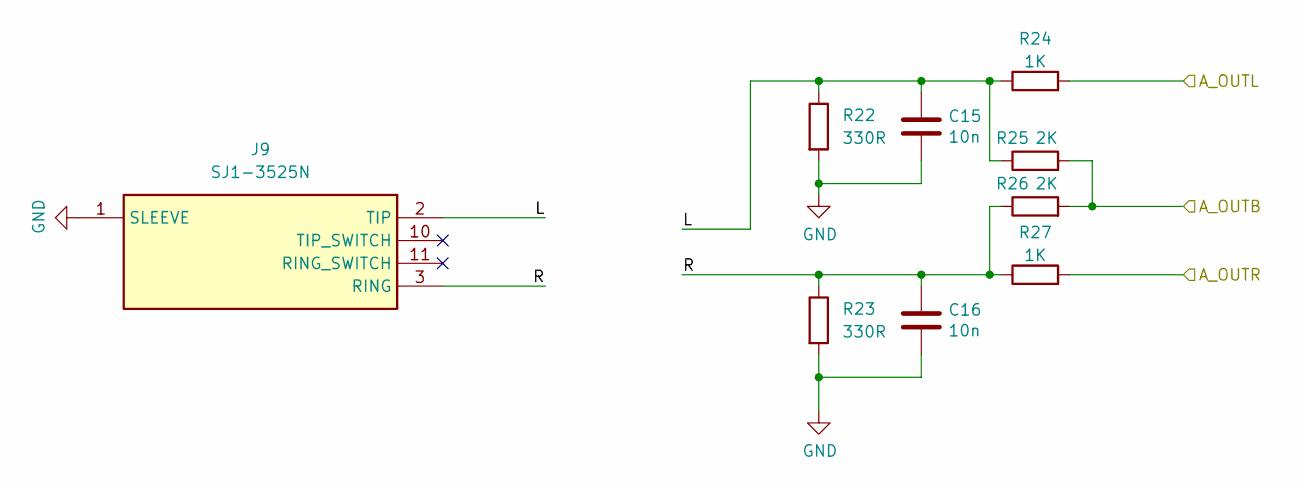
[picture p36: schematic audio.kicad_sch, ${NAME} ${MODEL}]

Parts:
C15, C16: 10n; Combined 0805 CR
J9: SJ1-3525N; SJ13525N; Mouser Part Number 490-SJ1-3525N
R22, R23: 330R; Combined 0805 RE
R24, R27: 1K; Combined 0805 RE
R25, R26: 2K; Combined 0805 RE

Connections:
/Audio/L: C15.1, J9.2 (TIP), R22.1, R24.1, R25.1
/Audio/R: C16.1, J9.3 (RING), R23.1, R26.1, R27.1
/PGPIO26: R27.2; also elsewhere on the board
/PGPIO27: R24.2; also elsewhere on the board
/PGPIO28: R25.2, R26.2; also elsewhere on the board
GND: C15.2, C16.2, J9.1 (SLEEVE), R22.2, R23.2; also elsewhere on the board

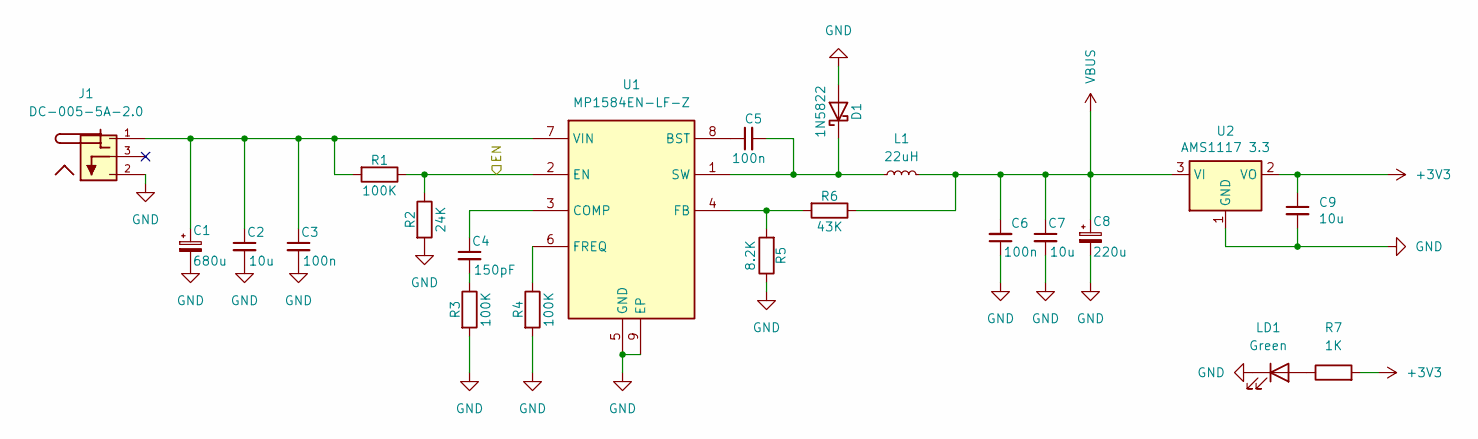
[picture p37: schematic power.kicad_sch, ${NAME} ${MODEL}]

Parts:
C1: 680u; Capacitor (Radial_D8.0mm_P3.50mm)
C2, C7, C9: 10u; Combined 0805 CR
C3, C5, C6: 100n; Combined 0805 CR
C4: 150pF; Combined 0805 CR
C8: 220u; Capacitor (Radial_D6.3mm_P2.50mm)
D1: 1N5822; D_DO-201AD_P5.08mm_Vertical_AnodeUp
J1: DC-005-5A-2.0; XKB_DC-005-5A-2.0; PARTREV A0
L1: 22uH; L_Radial_D9.5mm_P5.00mm_Fastron_07HVP
LD1: Green; Combined 0805 LD
R1, R3, R4: 100K; Combined 0805 RE
R2: 24K; Combined 0805 RE
R5: 8.2K; Combined 0805 RE
R6: 43K; Combined 0805 RE
R7: 1K; Combined 0805 RE
U1: MP1584EN-LF-Z; SOIC127P600X170-9N; Mouser Part Number 946-MP1584ENLFZ
U2: AMS1117 3.3; SOT-223

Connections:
+3V3: C9.1, R7.2, U2.2 (VO); also elsewhere on the board
/EN: R1.1, R2.1, U1.2 (EN)
GND: C1.2, C2.2, C3.2, C6.1, C7.2, C8.2, C9.2, D1.2 (A), J1.2, LD1.1 (K), R2.2, R3.2, R4.2, R5.1, U1.5 (GND), U1.9 (EP), U2.1 (GND); also elsewhere on the board
unnamed: C4.2, R3.1
unnamed: C5.2, D1.1 (K), L1.1, U1.1 (SW)
unnamed: LD1.2 (A), R7.1
unnamed: C5.1, U1.8 (BST)
unnamed: C4.1, U1.3 (COMP)
unnamed: R5.2, R6.2, U1.4 (FB)
unnamed: R4.1, U1.6 (FREQ)
unnamed: C1.1, C2.1, C3.1, J1.1, R1.2, U1.7 (VIN)
VBUS: C6.2, C7.1, C8.1, L1.2, R6.1, U2.3 (VI); also elsewhere on the board

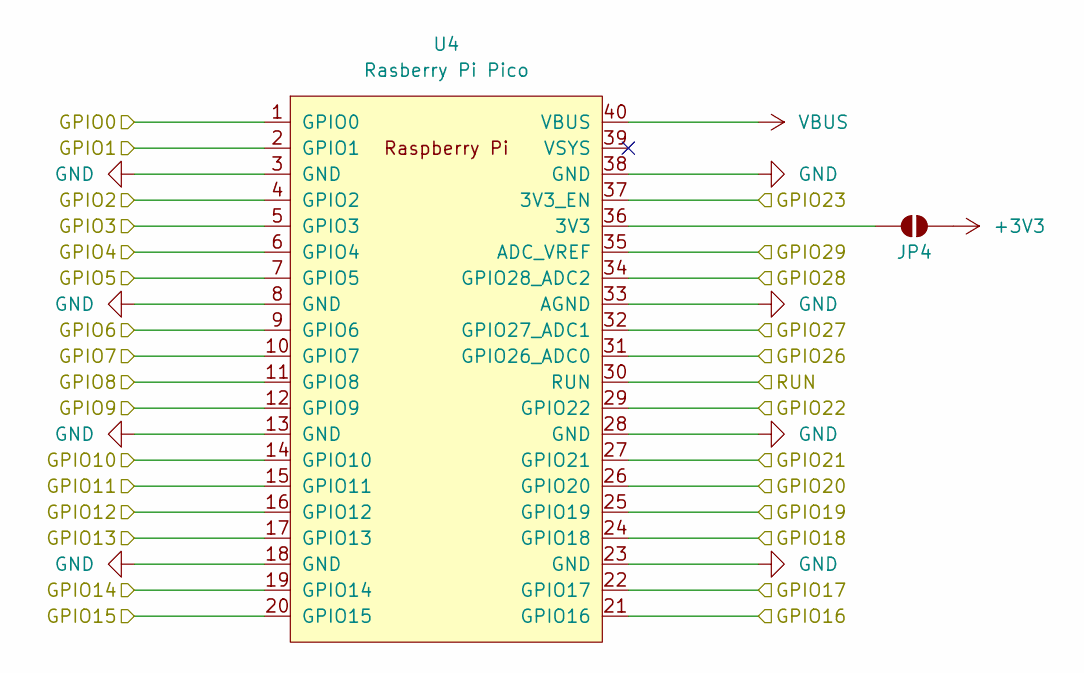
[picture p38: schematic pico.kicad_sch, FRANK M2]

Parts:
JP4: Jumper (Solder); Jumper (solder)
U4: Rasberry Pi Pico; Raspberry Pi Pico

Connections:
+3V3: JP4.2 (B); also elsewhere on the board
/PGPIO0: U4.1 (GPIO0); also elsewhere on the board
/PGPIO1: U4.2 (GPIO1); also elsewhere on the board
/PGPIO2: U4.4 (GPIO2); also elsewhere on the board
/PGPIO3: U4.5 (GPIO3); also elsewhere on the board
/PGPIO4: U4.6 (GPIO4); also elsewhere on the board
/PGPIO5: U4.7 (GPIO5); also elsewhere on the board
/PGPIO6: U4.9 (GPIO6); also elsewhere on the board
/PGPIO7: U4.10 (GPIO7); also elsewhere on the board
/PGPIO8: U4.11 (GPIO8); also elsewhere on the board
/PGPIO9: U4.12 (GPIO9); also elsewhere on the board
/PGPIO10: U4.14 (GPIO10); also elsewhere on the board
/PGPIO11: U4.15 (GPIO11); also elsewhere on the board
/PGPIO12: U4.16 (GPIO12); also elsewhere on the board
/PGPIO13: U4.17 (GPIO13); also elsewhere on the board
/PGPIO14: U4.19 (GPIO14); also elsewhere on the board
/PGPIO15: U4.20 (GPIO15); also elsewhere on the board
/PGPIO16: U4.21 (GPIO16); also elsewhere on the board
/PGPIO17: U4.22 (GPIO17)
/PGPIO17_1: U4.22 (GPIO17)
/PGPIO18: U4.24 (GPIO18); also elsewhere on the board
/PGPIO19: U4.25 (GPIO19); also elsewhere on the board
/PGPIO20: U4.26 (GPIO20); also elsewhere on the board
/PGPIO21: U4.27 (GPIO21); also elsewhere on the board
/PGPIO22: U4.29 (GPIO22); also elsewhere on the board
/PGPIO23: U4.37 (3V3_EN)
/PGPIO23_1: U4.37 (3V3_EN)
/PGPIO26: U4.31 (GPIO26_ADC0); also elsewhere on the board
/PGPIO27: U4.32 (GPIO27_ADC1); also elsewhere on the board
/PGPIO28: U4.34 (GPIO28_ADC2); also elsewhere on the board
/PGPIO29: U4.35 (ADC_VREF)
/PGPIO29_1: U4.35 (ADC_VREF)
/PRUN: U4.30 (RUN)
/PRUN_1: U4.30 (RUN)
GND: U4.3 (GND), U4.8 (GND), U4.13 (GND), U4.18 (GND), U4.23 (GND), U4.28 (GND), U4.33 (AGND), U4.38 (GND); also elsewhere on the board
unnamed: JP4.1 (A), U4.36 (3V3)
VBUS: U4.40 (VBUS); also elsewhere on the board

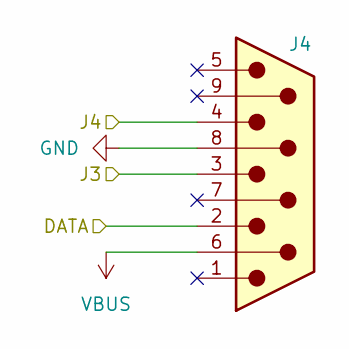
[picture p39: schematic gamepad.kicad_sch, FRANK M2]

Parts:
J4: D-SUB 9 Male; D-SUB (9 pin, male, top mount)

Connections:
/PGPIO14: J4.4; also elsewhere on the board
/PGPIO15: J4.3; also elsewhere on the board
/PGPIO16: J4.2; also elsewhere on the board
GND: J4.8; also elsewhere on the board
VBUS: J4.6; also elsewhere on the board

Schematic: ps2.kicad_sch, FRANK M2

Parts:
C10: 100n; Combined 0805 CR
J2: MDC-036; MiniDIN (6 Pin, female)
R8, R9: 1K; Combined 0805 RE

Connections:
+3V3: R8.2, R9.2; also elsewhere on the board
/PGPIO0: J2.5, R8.1; also elsewhere on the board
/PGPIO1: J2.1, R9.1; also elsewhere on the board
GND: C10.2, J2.3; also elsewhere on the board
VBUS: C10.1, J2.4; also elsewhere on the board

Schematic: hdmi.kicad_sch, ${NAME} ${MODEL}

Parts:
C12: 100n; Combined 0805 CR
C13: 470pF; Combined 0805 CR
D2: 1N5819; Diode (SOD81 P2.54mm Vertical AnodeUp)
J5: DC3RX19JA2; HDMI (female)
J6: D-SUB 15 Female; D-SUB (15 pin, female)
J7: RCA-103; RCA
JP1, JP2, JP3: Jumper (Solder); Jumper (solder)
R10, R11, R12, R13, R14, R15, R16, R17: 220R; Combined 0805 RE
R18: 75R; Combined 0805 RE

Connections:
/PGPIO6: R10.2; also elsewhere on the board
/PGPIO7: R11.2; also elsewhere on the board
/PGPIO8: R12.2; also elsewhere on the board
/PGPIO9: R13.2; also elsewhere on the board
/PGPIO10: R14.2; also elsewhere on the board
/PGPIO11: R15.2; also elsewhere on the board
/PGPIO12: R16.2; also elsewhere on the board
/PGPIO13: R17.2, R18.1; also elsewhere on the board
/Video Out/VGA_B: J5.12 (CLKN), J6.3, JP1.1 (A), R10.1
/Video Out/VGA_BH: J5.10 (CLKP), JP1.2 (B), R11.1
/Video Out/VGA_G: J5.9 (D0N), J6.2, JP2.1 (A), R12.1
/Video Out/VGA_GH: J5.7 (D0P), JP2.2 (B), R13.1
/Video Out/VGA_HS: J5.3 (D2N), J6.13, R16.1
/Video Out/VGA_R: J5.6 (D1N), J6.1, JP3.1 (A), R14.1
/Video Out/VGA_RH: J5.4 (D1P), JP3.2 (B), R15.1
/Video Out/VGA_VS: J5.1 (D2P), J6.14, R17.1
GND: C12.2, C13.2, J5.2 (G_D2), J5.5 (G_D1), J5.8 (G_D0), J5.11 (G_CLK), J5.17 (G_DDC/CEC), J5.20 (SHIELD1), J5.21 (SHIELD2), J5.22 (SHIELD3), J5.23 (SHIELD4), J6.0, J6.5, J6.6, J6.7, J6.8, J6.10, J7.2; also elsewhere on the board
unnamed: C12.1, D2.1 (K), J5.18 (+5V)
unnamed: C13.1, J7.1, R18.2
VBUS: D2.2 (A); also elsewhere on the board

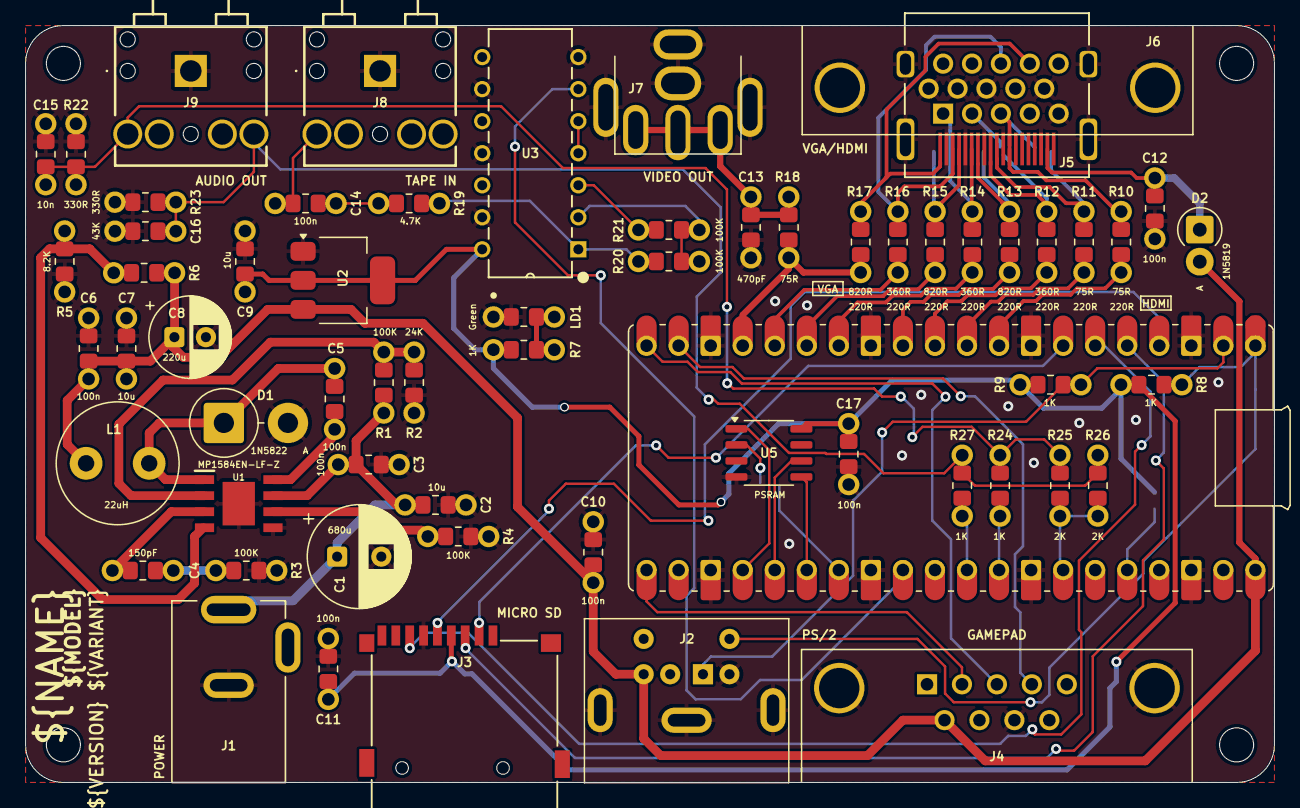
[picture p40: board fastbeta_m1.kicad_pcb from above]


Board: 2 copper layers, 99.0 x 60.0 mm, 71 parts (5 on the bottom side), 57 nets.

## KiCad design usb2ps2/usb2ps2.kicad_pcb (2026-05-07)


Board: 2 copper layers, 54.0 x 30.0 mm, 22 parts (0 on the bottom side), 20 nets.

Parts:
C1, C2: 10u; Capacitor (0805)
CN1: UART; Pin Header (1x03)
D1, D2, D3, D4: 3V3; Diode (SOD-323)
H1, H2, H3, H4: MountingHole; Mounting Hole (2.7mm)
PS1: PS/2; MiniDIN (6 Pin, female)
R1, R2, R3, R4: 22R; Resistor (0805)
R5, R6, R7, R8: 100R; Resistor (0805)
RP1: RP 2040 Zero; Raspberry Pi Zero (on board)
USB1: USB_A_Stacked; USB Type A (stacked)

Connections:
/GPIO0: CN1.1, RP1.1 (0)
/GPIO1: CN1.2, RP1.2 (1)
/GPIO2: R1.1, RP1.3 (2)
/GPIO3: R3.1, RP1.4 (3)
/GPIO4: R2.1, RP1.5 (4)
/GPIO5: R4.1, RP1.6 (5)
/GPIO11: D2.1 (K), R8.2, RP1.12 (11)
/GPIO12: D4.1 (K), R7.2, RP1.13 (12)
/GPIO14: D1.1 (K), R5.2, RP1.15 (14)
/GPIO15: D3.1 (K), R6.2, RP1.16 (15)
/PS2 with Diodes/KB_CLK: PS1.5, R7.1
/PS2 with Diodes/KB_DATA: PS1.1, R8.1
/PS2 with Diodes/MS_CLK: PS1.6, R6.1
/PS2 with Diodes/MS_DATA: PS1.2, R5.1
GND: C1.2, C2.2, CN1.3, D1.2 (A), D2.2 (A), D3.2 (A), D4.2 (A), PS1.3, RP1.22 (GND), USB1.4 (GND1), USB1.8 (GND2), USB1.9 (Shield)
unnamed: R1.2, USB1.3 (D1+)
unnamed: R3.2, USB1.2 (D1-)
unnamed: R2.2, USB1.7 (D2+)
unnamed: R4.2, USB1.6 (D2-)
VBUS: C1.1, C2.1, PS1.4, RP1.23 (5V), USB1.1 (VBUS1), USB1.5 (VBUS2)

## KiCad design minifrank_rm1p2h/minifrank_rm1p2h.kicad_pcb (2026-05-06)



Board: 4 copper layers, 85.8 x 85.8 mm, 204 parts (4 on the bottom side), 148 nets.

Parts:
C1, C2, C8, C9, C28, C36, C37, C41, C44, C60, C62, C63, C64, C65, C66, C69, C70: 10u; Capacitor (0805)
C3, C4, C5, C6, C10, C11, C12, C14, C15, C16, C17, C18, C19, C20, C21, C22, C26, C27, C29, C30, C31, C32, C33, C34, C35, C39, C40, C58, C61, C71: 100n; Capacitor (0805)
C7, C13, C23, C24, C25, C46, C48, C50: 4.7u; Capacitor (0805)
C38, C42, C53, C54, C55, C56, C59: 1u; Capacitor (0805)
C43: 1n; Capacitor (0805)
C45, C47, C49: 220n; Capacitor (0805)
C51, C52: 15p; Capacitor (0805)
C57: 47u; Capacitor (0805)
C67, C68: 47n; Capacitor (0805)
D1, D3, D4, D5, D6, D7: 3V3; Diode (SOD-323)
D2: 1N4148; Diode (SOD-323)
D8: 1N5819WS; Diode (SOD-323)
FB1, FB2: 220R; Inductor (0805)
H1, H2, H3, H4: MountingHole; Mounting Hole (2.7mm)
J1: UART; Pin Header (1x03)
J2: PWR; Pin Header (1x03)
J3, J11: D-SUB 9 Male; D-SUB (9 pin, male, top mount)
J4: USB4215-03-A; USB Type C
J5: 0475710001; MicroSD (SMD, short)
J6: 104031-0811; MicroSD (SMD, long)
J7: PAM L; Connector Female 1.25 JST 2P
J8: PAM R; Connector Female 1.25 JST 2P
J9, J10: PJ-320D; Jack (3.5mm, PJ-320D)
J12: MDC-036; MiniDIN (6 Pin, female)
J13: SS-52100-004; USB Type A (stacked)
J14: DC3RX19JA2; HDMI (female)
J15: Pin Header 1x08; Connector Female 1.25 JST 8P
JP1: Main Jumpers; SW_DS05-127-2-04BK-SMT-TR
JP2: Mouse CLK; Jumper (solder)
JP3: Mouse DATA; Jumper (solder)
L1: 3.3u; Inductor (0806)
LD1: Power; LED (0805)
LD2: Blue; LED (0805)
Q1, Q2: BC850; SOT-23
R1, R7, R9, R13, R14, R17, R18, R19, R31, R34, R48, R70, R71: 1K; Resistor (0805)
R2, R5: 5.1K; Resistor (0805)
R3, R4, R22, R23, R24, R25: 22R; Resistor (0805)
R6: 1M; Resistor (0805)
R8, R10, R11, R26, R27, R32, R33, R53, R54, R55, R56, R57, R58, R60, R62, R65, R68, R69: 10K; Resistor (0805)
R12, R15, R16, R20, R21, R44, R45: 100R; Resistor (0805)
R28: 33; Resistor (0805)
R29, R30: 27R; Resistor (0805)
R35, R37, R39: 800R; Resistor (0805)
R36, R38, R40: 400R; Resistor (0805)
R41, R42, R43: 75R; Resistor (0805)
R46, R47, R51, R52, R66, R67, R72, R73: 2K; Resistor (0805)
R49, R50: 4.7K; Resistor (0805)
R59, R64: 20K; Resistor (0805)
R61, R63: 47K; Resistor (0805)
R74, R75: 470R; Resistor (0805)
S1: Reset; TACT-SIDE-4623
S2: MSK12C02; Switch (MSK12C02)
S3: TS-1233; TACT-SIDE-4623
TP1: MS9288_SCL; TestPoint (Pad 1.0x1.0mm)
TP2: MS9288_SDA; TestPoint (Pad 1.0x1.0mm)
U1: NCP1117 3.3; SOT-223
U2: USBLC6-2SC6; SOT-23-6
U3: MW7211A; SOP-16
U4: 74HC4052D; SOP-16
U5: TS3USB221RSER; UQFN-10
U6: RP2350; QFN 60 (RP2350A)
U7: ESP-PSRAM32; SO-8
U8: W25Q128JVS; SOIC-8
U9: AMS1117-3.3; SOT-223
U10: AMS1117-1.8; SOT-223
U11: MS9288A; QFN 48
U12: PAM8403D; SOP-16
U13: LM358; SO-8
U14: TDA1387T; SO-8
X1: 24.576 MHz; Crystal (2520)
Y1: ASE-12MHz; Crystal (3225, active)

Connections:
+1V1: C12.1, C13.1, C14.1, C25.1, L1.1, U6.6 (DVDD), U6.23 (DVDD), U6.39 (DVDD), U6.50 (VREG_FB)
+3V3: C1.1, C3.2, C4.1, C10.2, C11.2, C15.1, C16.1, C17.1, C18.1, C19.1, C20.1, C21.1, C22.1, C24.1, C26.1, C27.1, J2.1, J5.P4 (VDD), J6.4 (VDD), JP1.8, R7.2, R8.1, R9.1, R27.1, R28.1, R32.2, R33.1, U1.2 (VO), U4.16 (VCC), U5.10 (VCC), U6.1 (IOVDD), U6.11 (IOVDD), U6.20 (IOVDD), U6.30 (IOVDD), U6.38 (IOVDD), U6.44 (ADC_AVDD), U6.45 (IOVDD), U6.49 (VREG_VIN), U6.53 (USB_OTP_VDD), U6.54 (QSPI_IOVDD), U7.8 (VCC), U8.8 (VCC), Y1.1 (EN), Y1.4 (Vdd)
/AMP_IN_L: C53.2, C62.1, R56.1, U4.13 (1Z)
/AMP_IN_R: C54.2, C64.1, R57.1, U4.3 (2Z)
/AUDIOSW: JP1.1, R26.2, U4.10 (S0)
/Audio Out/AMP_OUTL: C63.2, J9.T, R59.2
/Audio Out/AMP_OUTR: C65.2, J9.R, R64.2
/Audio Out/AMP_PAM_OUTL_M: J7.2, U12.3 (-OUTL)
/Audio Out/AMP_PAM_OUTL_P: J7.1, U12.1 (+OUT_L)
/Audio Out/AMP_PAM_OUTR_M: J8.2, U12.14 (-OUT_R)
/Audio Out/AMP_PAM_OUTR_P: J8.1, U12.16 (+OUT_R)
/D+: R29.1, U5.8 (D+)
/D-: R30.1, U5.7 (D-)
/DAT1: J5.P8 (DAT1), J6.8 (DAT1)
/DAT2: J5.P1 (DAT2), J6.1 (DAT2)
/GPIO0: D4.1 (K), J1.2, R15.2, U6.2 (GPIO0)
/GPIO1: D5.1 (K), J1.3, R16.2, U6.3 (GPIO1)
/GPIO2: J5.P5 (CLK), J6.5 (CLK), U6.4 (GPIO2)
/GPIO3: J5.P3 (CMD), J6.3 (CMD), U6.5 (GPIO3)
/GPIO4: J5.P7 (DAT0), J6.7 (DAT0), U6.7 (GPIO4)
/GPIO5: J5.P2 (CD/DAT3), J6.2 (DAT3/CD), U6.8 (GPIO5)
/GPIO6: J15.3, R35.1, U6.9 (GPIO6)
/GPIO7: R36.1, U6.10 (GPIO7)
/GPIO8: J15.4, R37.1, U6.12 (GPIO8)
/GPIO9: J15.8, R38.1, U6.13 (GPIO9)
/GPIO10: J15.5, R39.1, U6.14 (GPIO10)
/GPIO11: R40.1, U6.15 (GPIO11)
/GPIO12: J15.6, R44.1, U6.16 (GPIO12)
/GPIO13: J15.7, R45.1, U6.17 (GPIO13)
/GPIO14: J3.4, J11.4, JP2.2 (B), U6.18 (GPIO14)
/GPIO15: J3.3, J11.3, JP3.2 (B), U6.19 (GPIO15)
/GPIO16: D3.1 (K), R13.1, U6.27 (GPIO16)
/GPIO17: D1.1 (K), R1.1, U6.28 (GPIO17)
/GPIO19: R32.1, U6.31 (GPIO19), U7.1 (~CE)
/GPIO22: Q1.3 (C), R9.2, U6.34 (GPIO22)
/GPIO26: R71.2, U6.40 (GPIO26_ADC0), U14.3 (DATA)
/GPIO27: R70.2, U6.41 (GPIO27_ADC1), U14.1 (SCLK)
/GPIO28: R66.1, R67.1, U6.42 (GPIO28_ADC2), U14.2 (LRCK)
/HUB_D+: U3.11 (DPU), U5.1 (1D+)
/HUB_D-: U3.10 (DMU), U5.2 (1D-)
/KB_CLK: J12.5, R14.2, R15.1
/KB_DATA: J12.1, R16.1, R17.2
/MONO_L: C56.1, JP1.3, R51.1, R56.2
/MONO_R: C59.1, JP1.6, R52.1, R57.2
/MS_CLK: J12.6, R19.2, R21.1
/MS_CLK_3V: D7.1 (K), JP2.1 (A), R21.2
/MS_DATA: J12.2, R18.2, R20.1
/MS_DATA_3V: D6.1 (K), JP3.1 (A), R20.2
/PWM_OUT_L: R69.2, R73.1, U4.12 (1Y0)
/PWM_OUT_R: R68.2, R72.1, U4.1 (2Y0)
/RP2350A/QSPI_SCLK: U6.56 (QSPI_SCLK), U7.6 (SCLK), U8.6 (CLK)
/RP2350A/QSPI_SD0: U6.57 (QSPI_SD0), U7.5 (SI/SIO), U8.5 (DI(IO0))
/RP2350A/QSPI_SD1: U6.59 (QSPI_SD1), U7.2 (SO/SIO), U8.2 (DO(IO1))
/RP2350A/QSPI_SD2: U6.58 (QSPI_SD2), U7.3 (SIO2), U8.3 (IO2)
/RP2350A/QSPI_SD3: U6.55 (QSPI_SD3), U7.7 (SIO3), U8.7 (IO3)
/RP2350A/QSPI_SS: R31.1, R33.2, U6.60 (QSPI_SS), U8.1 (~CS)
/RP2350A/VREG_AVDD: C23.1, R28.2, U6.46 (VREG_AVDD)
/RP2350A/VREG_LX: L1.2, U6.48 (VREG_LX)
/RP2350A/XIN: U6.21 (XIN), Y1.3 (OUT)
/RP2350A/~USB_BOOT: R31.2, S3.2
/RUN: S1.1, U6.26 (RUN)
/SHND: JP1.4, R54.2, U12.12 (SHND)
/TDA_L: R75.2, U4.14 (1Y1), U14.6 (A_LEFT)
/TDA_R: R74.1, U4.5 (2Y1), U14.8 (A_RIGHT)
/USBMPXSW: JP1.2, R27.2, U5.9 (S)
/USB_D1+: R22.1, U3.8 (DP3)
/USB_D1-: R24.1, U3.7 (DM3)
/USB_D2+: R23.1, U3.6 (DP2)
/USB_D2-: R25.1, U3.5 (DM2)
/UTC_D+: U2.4 (I/O2), U5.3 (2D+)
/UTC_D-: U2.6 (I/O1), U5.4 (2D-)
/VGA/ALIN: C53.1, U11.30 (ALIN)
/VGA/AMS_1V8: C32.1, C41.1, C42.1, FB2.1, U10.2 (VO), U11.7 (AVDD18), U11.16 (AVDD18), U11.21 (AVDD18)
/VGA/AMS_1V8A: C30.1, C31.1, C44.1, FB2.2, U11.1 (AVDD18_ADC), U11.41 (AVDD18_ADC), U11.46 (AVDD18_ADC)
/VGA/AMS_3V3: C34.1, C37.1, C38.1, FB1.2, U9.2 (VO), U11.5 (DVDD33), U11.11 (DVDD33), U11.24 (DVDD33), U11.36 (DVDD33)
/VGA/AMS_3V3A: C28.1, C33.1, FB1.1, U11.12 (AVDD33), U11.38 (AVDD33), U11.43 (AVDD33), U11.47 (AVDD33)
/VGA/ARIN: C54.1, U11.33 (ARIN)
/VGA/B: C29.1, U11.39 (B/Pb)
/VGA/DCCSCL: J14.15 (SCL), R46.1, U11.10 (DCCSCL)
/VGA/DDCSDA: J14.16 (SDA), R47.1, U11.9 (DDCSDA)
/VGA/G: C35.1, U11.44 (G/Y)
/VGA/HPDT: J14.19 (HOT_PLUG_DET), U11.8 (HotPlugDetect)
/VGA/R: C39.1, U11.48 (R/Pr)
/VGA/SCL: R49.1, TP1.1, U11.28 (SCL)
/VGA/SDA: R50.1, TP2.1, U11.29 (SDA)
/VGA/SOG_G: C35.2, C43.2, R37.2, R38.2, R42.1
/VGA/TMDS_CLK+: J14.10 (CLKP), U11.15 (TMDS_CLK+)
/VGA/TMDS_CLK-: J14.12 (CLKN), U11.14 (TMDS_CLK-)
/VGA/TMDS_D0+: J14.7 (D0P), U11.18 (TMDS-D0+)
/VGA/TMDS_D0-: J14.9 (D0N), U11.17 (TMDS_D0-)
/VGA/TMDS_D1+: J14.4 (D1P), U11.20 (TMDS_D1+)
/VGA/TMDS_D1-: J14.6 (D1N), U11.19 (TMDS_D1-)
/VGA/TMDS_D2+: J14.1 (D2P), U11.23 (TMDS_D2+)
/VGA/TMDS_D2-: J14.3 (D2N), U11.22 (TMDS_D2-)
GND: C1.2, C2.2, C3.1, C4.2, C6.2, C7.2, C8.2, C9.2, C10.1, C11.1, C12.2, C13.2, C14.2, C15.2, C16.2, C17.2, C18.2, C19.2, C20.2, C21.2, C22.2, C23.2, C24.2, C25.2, C26.2, C27.2, C28.2, C30.2, C31.2, C32.2, C33.2, C34.2, C36.2, C37.2, C38.2, C40.2, C41.2, C42.2, C44.2, C45.2, C46.2, C47.2, C48.2, C49.2, C50.2, C51.2, C52.2, C55.2, C57.2, C58.2, C60.1, C61.1, C66.1, C67.2, C68.2, C69.2, C70.2, C71.2, D1.2 (A), D3.2 (A), D4.2 (A), D5.2 (A), D6.2 (A), D7.2 (A), J1.1, J2.2, J3.8, J4.1 (GND), J4.12 (GND), J5.G1 (GND_1), J5.G2 (GND_2), J5.G3 (GND_3), J5.P6 (VSS), J6.6 (VSS), J9.S, J10.S, J11.8, J12.3, J13.4 (GND1), J13.8 (GND2), J13.9 (Shield), J14.2 (G_D2), J14.5 (G_D1), J14.8 (G_D0), J14.11 (G_CLK), J14.17 (G_DDC/CEC), J14.20 (SHIELD1), J14.21 (SHIELD2), J14.22 (SHIELD3), J14.23 (SHIELD4), J15.1, JP1.5, JP1.7, LD1.1 (K), LD2.1 (K), Q1.2 (E), Q2.2 (E), R2.1, R5.1, R6.2, R12.2, R26.1, R41.2, R42.2, R43.2, R48.1, R51.2, R52.2, R59.1, R64.1, R65.1, R72.2, R73.2, R74.2, R75.1, S1.2, S3.1, U1.1 (GND), U2.2 (GND), U3.15 (GND), U3.16 (GND), U4.2 (2Y2), U4.4 (2Y3), U4.6 (~E), U4.7 (VEE), U4.8 (GND), U4.9 (S1), U4.11 (1Y3), U4.15 (1Y2), U5.5 (GND), U5.6 (~OE), U6.47 (VREG_PGND), U6.61 (GND), U7.4 (VSS), U8.4 (GND), U9.1 (GND), U10.1 (GND), U11.2 (GND), U11.6 (GND), U11.27 (GND), U11.40 (GND), U11.45 (GND), U11.49 (EP), U12.2 (PGND), U12.11 (GND), U12.15 (PGND), U13.4 (V-), U14.4 (AGND), X1.2 (GND), X1.4 (GND), Y1.2 (GND)
GPIO25: R34.2, U6.37 (GPIO25)
unnamed: C5.1, J10.T, R12.1
unnamed: C5.2, R11.1
unnamed: C29.2, R35.2, R36.2, R43.1
unnamed: C39.2, R39.2, R40.2, R41.1
unnamed: C56.2, R53.2
unnamed: C59.2, R55.2
unnamed: C62.2, R60.2
unnamed: C63.1, R61.1, U13.7
unnamed: C64.2, R62.2
unnamed: C65.1, R63.1, U13.1
unnamed: C67.1, R66.2, R68.1, R71.1
unnamed: C68.1, R67.2, R69.1, R70.1
unnamed: D2.2 (A), Q2.3 (C), R8.2, R10.1
unnamed: D2.1 (K), Q2.1 (B), R11.2
unnamed: D8.1 (K), J14.18 (+5V)
unnamed: J3.2, R1.2
unnamed: J4.4 (CC1), R2.2
unnamed: J4.10 (CC2), R5.2
unnamed: J4.5 (DN2), J4.7 (DN1), R3.2
unnamed: J4.6 (DP1), J4.8 (DP2), R4.2
unnamed: J4.13 (SHIELD), R6.1
unnamed: J11.2, R13.2
unnamed: J13.3 (D1+), R22.2
unnamed: J13.2 (D1-), R24.2
unnamed: J13.7 (D2+), R23.2
unnamed: J13.6 (D2-), R25.2
unnamed: LD1.2 (A), R7.1
unnamed: LD2.2 (A), R34.1
unnamed: Q1.1 (B), R10.2
unnamed: R3.1, U2.1 (I/O1)
unnamed: R4.1, U2.3 (I/O2)
unnamed: J4.2 (VBUS), J4.11 (VBUS), S2.2 (B)
unnamed: U3.12 (VD33), U3.14 (VD3)
unnamed: R30.2, U6.51 (USB_DM)
unnamed: R29.2, U6.52 (USB_DP)
unnamed: R44.2, U11.34 (HSIN)
unnamed: C49.1, C50.1, U11.37 (REFP)
unnamed: C45.1, C46.1, U11.31 (REFQ0)
unnamed: C47.1, C48.1, U11.32 (REFQ1)
unnamed: C43.1, U11.42 (SOG/Y)
unnamed: R48.2, U11.13 (SWREF1k)
unnamed: R45.2, U11.35 (VSIN)
unnamed: C52.1, U11.25 (XTI), X1.1 (OSC)
unnamed: C51.1, U11.26 (XTO), X1.3 (OSC)
unnamed: R53.1, U12.7 (INL)
unnamed: R55.1, U12.10 (INR)
unnamed: C58.1, U12.8 (VREF)
unnamed: C66.2, R58.1, R65.2, U13.3 (+), U13.5 (+)
unnamed: R62.1, R63.2, U13.2 (-)
unnamed: R60.1, R61.2, U13.6 (-)
unnamed: C69.1, U14.7 (FLT)
VBUS: C2.1, C6.1, C7.1, C8.1, C9.1, C36.1, C40.1, C55.1, C57.1, C60.2, C61.2, C70.1, C71.1, D8.2 (A), J2.3, J3.6, J11.6, J12.4, J13.1 (VBUS1), J13.5 (VBUS2), J15.2, R14.1, R17.1, R18.1, R19.1, R46.2, R47.2, R49.2, R50.2, R54.1, R58.2, S2.3 (A), U1.3 (VI), U2.5 (VBUS), U3.13 (VDD5), U9.3 (VI), U10.3 (VI), U12.4 (PVDD), U12.5 (MUTE), U12.6 (VDD), U12.13 (PVDD), U13.8 (V+), U14.5 (VA)

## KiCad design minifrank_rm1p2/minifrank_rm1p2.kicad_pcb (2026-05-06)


Board: 4 copper layers, 99.0 x 65.5 mm, 159 parts (0 on the bottom side), 116 nets.

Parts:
C1, C2, C8, C9, C29, C31, C32, C33, C34, C35, C38, C39: 10u; Capacitor (0805)
C3, C4, C5, C6, C10, C11, C12, C13, C15, C16, C17, C18, C19, C20, C21, C22, C23, C27, C28, C30, C40: 100n; Capacitor (0805)
C7, C14, C24, C25, C26: 4.7u; Capacitor (0805)
C36, C37: 47n; Capacitor (0805)
D1, D3, D4, D5, D6, D7: 3V3; Diode (SOD-323)
D2: 1N4148; Diode (SOD-323)
H1, H2, H3, H4: MountingHole; Mounting Hole (2.7mm)
J1: UART; Pin Header (1x03)
J2: PWR; Pin Header (1x03)
J3, J9: D-SUB 9 Male; D-SUB (9 pin, male, top mount)
J4: USB4215-03-A; USB Type C
J5: 0475710001; MicroSD (SMD, short)
J6: 104031-0811; MicroSD (SMD, long)
J7, J8: PJ-320D; Jack (3.5mm, PJ-320D)
J10: MDC-036; MiniDIN (6 Pin, female)
J11: SS-52100-004; USB Type A (stacked)
J12: DC3RX19JA2; HDMI (female)
J13: D-SUB 15 Female; D-SUB (15 pin, female)
J14: Pin Header 1x08; Connector Female ZH 1.50mm (8 pins)
JP1: Main Jumpers; SW_DS05-127-2-04BK-SMT-TR
L1: 3.3u; Inductor (0806)
LD1: Power; LED (0805)
LD2: Blue; LED (0805)
Q1, Q2: BC850; SOT-23
R1, R7, R9, R13, R14, R17, R18, R19, R41, R45, R49, R50, R51, R70, R71: 1K; Resistor (0805)
R2, R5: 5.1K; Resistor (0805)
R3, R4, R22, R23, R24, R25: 22R; Resistor (0805)
R6: 1M; Resistor (0805)
R8, R10, R11, R34, R35, R42, R43, R56, R57, R58, R60, R62, R65, R68, R69: 10K; Resistor (0805)
R12, R15, R16, R20, R21, R52, R53: 100R; Resistor (0805)
R26, R27, R28, R29, R30, R31, R32, R33: 270R; Resistor (0805)
R36, R39: 150R; Resistor (0805)
R37: 33; Resistor (0805)
R38, R40: 33R; Resistor (0805)
R44: 0R; Resistor (0805)
R46, R47, R48: 330R; Resistor (0805)
R54, R55, R66, R67, R72, R73: 2K; Resistor (0805)
R59, R64: 20K; Resistor (0805)
R61, R63: 47K; Resistor (0805)
R74, R75: 470R; Resistor (0805)
S1: Reset; TACT-SIDE-4623
S2: TS-1233; TACT-SIDE-4623
U1: NCP1117 3.3; SOT-223
U2: USBLC6-2SC6; SOT-23-6
U3: MW7211A; SOP-16
U4: 74HC4052D; 74HC4052D653
U5: TS3USB221RSER; UQFN-10
U6: RP2350; QFN 60 (RP2350A)
U7: ESP-PSRAM32; SO-8
U8: W25Q128JVS; SOIC-8
U9: LM358; SO-8
U10: TDA1387T; SO-8
Y1: ASE-12MHz; Crystal (3225, active)

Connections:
+1V1: C13.1, C14.1, C15.1, C26.1, L1.1, U6.6 (DVDD), U6.23 (DVDD), U6.39 (DVDD), U6.50 (VREG_FB)
+3V3: C1.1, C3.2, C4.1, C11.2, C12.2, C16.1, C17.1, C18.1, C19.1, C20.1, C21.1, C22.1, C23.1, C25.1, C27.1, C28.1, J2.1, J5.P4 (VDD), J6.4 (VDD), JP1.8, R7.2, R8.1, R9.1, R35.1, R37.1, R42.2, R43.1, U1.2 (VO), U4.16 (VCC), U5.10 (VCC), U6.1 (IOVDD), U6.11 (IOVDD), U6.20 (IOVDD), U6.30 (IOVDD), U6.38 (IOVDD), U6.44 (ADC_AVDD), U6.45 (IOVDD), U6.49 (VREG_VIN), U6.53 (USB_OTP_VDD), U6.54 (QSPI_IOVDD), U7.8 (VCC), U8.8 (VCC), Y1.1 (EN), Y1.4 (Vdd)
/AMP_IN_L: C31.1, R56.1, U4.13 (1Z)
/AMP_IN_R: C33.1, R57.1, U4.3 (2Z)
/AUDIOSW: JP1.1, R34.2, U4.10 (S0)
/Audio Out/AMP_OUTL: C32.2, J7.T, R59.2
/Audio Out/AMP_OUTR: C34.2, J7.R, R64.2
/D+: R36.1, R38.1, U5.8 (D+)
/D-: R39.1, R40.1, U5.7 (D-)
/GPIO0: D4.1 (K), J1.2, R15.2, U6.2 (GPIO0)
/GPIO1: D5.1 (K), J1.3, R16.2, U6.3 (GPIO1)
/GPIO2: J5.P5 (CLK), J6.5 (CLK), U6.4 (GPIO2)
/GPIO3: J5.P3 (CMD), J6.3 (CMD), U6.5 (GPIO3)
/GPIO4: J5.P7 (DAT0), J6.7 (DAT0), U6.7 (GPIO4)
/GPIO5: J5.P2 (CD/DAT3), J6.2 (DAT3/CD), U6.8 (GPIO5)
/GPIO6: J14.3, R26.2, R51.1, U6.9 (GPIO6)
/GPIO7: R27.2, R48.1, U6.10 (GPIO7)
/GPIO8: J14.4, R28.2, R50.1, U6.12 (GPIO8)
/GPIO9: J14.8, R29.2, R47.1, U6.13 (GPIO9)
/GPIO10: J14.5, R30.2, R49.1, U6.14 (GPIO10)
/GPIO11: R31.2, R46.1, U6.15 (GPIO11)
/GPIO12: J14.6, R32.2, R52.2, U6.16 (GPIO12)
/GPIO13: J14.7, R33.2, R53.2, U6.17 (GPIO13)
/GPIO14: J3.4, J9.4, JP1.6, U6.18 (GPIO14)
/GPIO15: J3.3, J9.3, JP1.5, U6.19 (GPIO15)
/GPIO16: D3.1 (K), R13.1, U6.27 (GPIO16)
/GPIO17: D1.1 (K), R1.1, U6.28 (GPIO17)
/GPIO19: R42.1, U6.31 (GPIO19), U7.1 (~CE)
/GPIO22: Q1.3 (C), R9.2, U6.34 (GPIO22)
/GPIO26: R71.2, U6.40 (GPIO26_ADC0), U10.3 (DATA)
/GPIO27: R70.2, U6.41 (GPIO27_ADC1), U10.1 (SCLK)
/GPIO28: R66.1, R67.1, U6.42 (GPIO28_ADC2), U10.2 (LRCK)
/HUB_D+: U3.11 (DPU), U5.1 (1D+)
/HUB_D-: U3.10 (DMU), U5.2 (1D-)
/KB_CLK: J10.5, R14.2, R15.1
/KB_DATA: J10.1, R16.1, R17.2
/MS_CLK: J10.6, R19.2, R21.1
/MS_CLK_3V: D7.1 (K), JP1.3, R21.2
/MS_DATA: J10.2, R18.2, R20.1
/MS_DATA_3V: D6.1 (K), JP1.4, R20.2
/PWM_OUT_L: R69.2, R73.1, U4.12 (1Y0)
/PWM_OUT_R: R68.2, R72.1, U4.1 (2Y0)
/RP2350A/FLASH_SS: R43.2, R44.2, U8.1 (~CS)
/RP2350A/QSPI_SCLK: U6.56 (QSPI_SCLK), U7.6 (SCLK), U8.6 (CLK)
/RP2350A/QSPI_SD0: U6.57 (QSPI_SD0), U7.5 (SI/SIO), U8.5 (DI(IO0))
/RP2350A/QSPI_SD1: U6.59 (QSPI_SD1), U7.2 (SO/SIO), U8.2 (DO(IO1))
/RP2350A/QSPI_SD2: U6.58 (QSPI_SD2), U7.3 (SIO2), U8.3 (IO2)
/RP2350A/QSPI_SD3: U6.55 (QSPI_SD3), U7.7 (SIO3), U8.7 (IO3)
/RP2350A/QSPI_SS: R41.1, R44.1, U6.60 (QSPI_SS)
/RP2350A/VREG_AVDD: C24.1, R37.2, U6.46 (VREG_AVDD)
/RP2350A/VREG_LX: L1.2, U6.48 (VREG_LX)
/RP2350A/XIN: U6.21 (XIN), Y1.3 (OUT)
/RP2350A/~USB_BOOT: R41.2, S2.2
/RUN: S1.1, U6.26 (RUN)
/SD Card/DAT1: J5.P8 (DAT1), J6.8 (DAT1)
/SD Card/DAT2: J5.P1 (DAT2), J6.1 (DAT2)
/TDA_L: R75.2, U4.14 (1Y1), U10.6 (A_LEFT)
/TDA_R: R74.1, U4.5 (2Y1), U10.8 (A_RIGHT)
/USBMPXSW: JP1.2, R35.2, U5.9 (S)
/USB_D1+: R22.1, U3.8 (DP3)
/USB_D1-: R24.1, U3.7 (DM3)
/USB_D2+: R23.1, U3.6 (DP2)
/USB_D2-: R25.1, U3.5 (DM2)
/UTC_D+: U2.4 (I/O2), U5.3 (2D+)
/UTC_D-: U2.6 (I/O1), U5.4 (2D-)
GND: C1.2, C2.2, C3.1, C4.2, C6.2, C7.2, C8.2, C9.2, C10.2, C11.1, C12.1, C13.2, C14.2, C15.2, C16.2, C17.2, C18.2, C19.2, C20.2, C21.2, C22.2, C23.2, C24.2, C25.2, C26.2, C27.2, C28.2, C29.1, C30.1, C35.1, C36.2, C37.2, C38.2, C39.2, C40.2, D1.2 (A), D3.2 (A), D4.2 (A), D5.2 (A), D6.2 (A), D7.2 (A), J1.1, J2.2, J3.8, J4.1 (GND), J4.12 (GND), J5.G1 (GND_1), J5.G2 (GND_2), J5.G3 (GND_3), J5.P6 (VSS), J6.6 (VSS), J7.S, J8.S, J9.8, J10.3, J11.4 (GND1), J11.8 (GND2), J11.9 (Shield), J12.2 (G_D2), J12.5 (G_D1), J12.8 (G_D0), J12.11 (G_CLK), J12.17 (G_DDC/CEC), J12.20 (SHIELD1), J12.21 (SHIELD2), J12.22 (SHIELD3), J12.23 (SHIELD4), J13.0, J13.5, J13.6, J13.7, J13.8, J13.10, J14.2, JP1.7, LD1.1 (K), LD2.1 (K), Q1.2 (E), Q2.2 (E), R2.1, R5.1, R6.2, R12.2, R34.1, R54.2, R55.2, R59.1, R64.1, R65.1, R72.2, R73.2, R74.2, R75.1, S1.2, S2.1, U1.1 (GND), U2.2 (GND), U3.15 (GND), U3.16 (GND), U4.2 (2Y2), U4.4 (2Y3), U4.6 (~E), U4.7 (VEE), U4.8 (GND), U4.9 (S1), U4.11 (1Y3), U4.15 (1Y2), U5.5 (GND), U5.6 (~OE), U6.47 (VREG_PGND), U6.61 (GND), U7.4 (VSS), U8.4 (GND), U9.4 (V-), U10.4 (AGND), Y1.2 (GND)
GPIO25: R45.2, U6.37 (GPIO25)
unnamed: C5.1, J8.T, R12.1
unnamed: C5.2, R11.1
unnamed: C31.2, R60.2
unnamed: C32.1, R61.1, U9.7
unnamed: C33.2, R62.2
unnamed: C34.1, R63.1, U9.1
unnamed: C36.1, R66.2, R68.1, R71.1
unnamed: C37.1, R67.2, R69.1, R70.1
unnamed: D2.2 (A), Q2.3 (C), R8.2, R10.1
unnamed: D2.1 (K), Q2.1 (B), R11.2
unnamed: J3.2, R1.2
unnamed: J4.4 (CC1), R2.2
unnamed: J4.10 (CC2), R5.2
unnamed: J4.5 (DN2), J4.7 (DN1), R3.2
unnamed: J4.6 (DP1), J4.8 (DP2), R4.2
unnamed: J4.13 (SHIELD), R6.1
unnamed: J9.2, R13.2
unnamed: J11.3 (D1+), R22.2
unnamed: J11.2 (D1-), R24.2
unnamed: J11.7 (D2+), R23.2
unnamed: J11.6 (D2-), R25.2
unnamed: J12.12 (CLKN), R26.1
unnamed: J12.10 (CLKP), R27.1
unnamed: J12.9 (D0N), R28.1
unnamed: J12.7 (D0P), R29.1
unnamed: J12.6 (D1N), R30.1
unnamed: J12.4 (D1P), R31.1
unnamed: J12.3 (D2N), R32.1
unnamed: J12.1 (D2P), R33.1
unnamed: J13.1, R46.2, R49.2
unnamed: J13.2, R47.2, R50.2
unnamed: J13.3, R48.2, R51.2
unnamed: J13.13, R52.1
unnamed: J13.14, R53.1
unnamed: LD1.2 (A), R7.1
unnamed: LD2.2 (A), R45.1
unnamed: Q1.1 (B), R10.2
unnamed: R3.1, U2.1 (I/O1)
unnamed: R4.1, U2.3 (I/O2)
unnamed: R54.1, R56.2
unnamed: R55.1, R57.2
unnamed: U3.12 (VD33), U3.14 (VD3)
unnamed: R39.2, R40.2, U6.51 (USB_DM)
unnamed: R36.2, R38.2, U6.52 (USB_DP)
unnamed: C35.2, R58.1, R65.2, U9.3 (+), U9.5 (+)
unnamed: R62.1, R63.2, U9.2 (-)
unnamed: R60.1, R61.2, U9.6 (-)
unnamed: C38.1, U10.7 (FLT)
VBUS: C2.1, C6.1, C7.1, C8.1, C9.1, C10.1, C29.2, C30.2, C39.1, C40.1, J2.3, J3.6, J4.2 (VBUS), J4.11 (VBUS), J9.6, J10.4, J11.1 (VBUS1), J11.5 (VBUS2), J12.18 (+5V), J14.1, R14.1, R17.1, R18.1, R19.1, R58.2, U1.3 (VI), U2.5 (VBUS), U3.13 (VDD5), U9.8 (V+), U10.5 (VA)

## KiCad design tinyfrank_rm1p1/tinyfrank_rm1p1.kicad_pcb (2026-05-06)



Board: 2 copper layers, 55.0 x 30.0 mm, 67 parts (3 on the bottom side), 65 nets.

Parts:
C1, C3, C5, C23, C24: 10u; Capacitor (0603)
C2, C7, C8, C9, C10, C11, C12, C13, C14, C15, C16, C17, C20, C25: 100n; Capacitor (0402)
C4, C6: 10n; Capacitor (0402)
C18, C19: 1u; Capacitor (0603)
C21, C22: 15p; Capacitor (0402)
H1, H2, H3, H4: MountingHole; Mounting Hole (2.7mm)
J1: PWR; Pin Header (1x03)
J2: 676430910; USB Type A (single)
J3: 0475710001; MicroSD (SMD, short)
J4: PJ-320D; Jack (3.5mm, PJ-320D)
J5: USB4215-03-A; USB Type C
J6: DC3RX19JA2; HDMI (female)
JP1: Jumper (Solder); Jumper (solder)
LD1: Blue; LED (0402)
LD2: Power; LED (0402)
R1, R2: 22R; Resistor (0402)
R3, R17: 1M; Resistor (0402)
R4, R8, R11, R13, R14, R18: 1K; Resistor (0402)
R5, R9: 330R; Resistor (0402)
R6, R7: 2K; Resistor (0402)
R10, R12: 27R; Resistor (0402)
R15, R16: 5.1K; Resistor (0402)
RN1, RN2: 270R; Resistor Array (4x0603)
S1: Reset; TACT-SIDE-4623
S2: Boot; TACT-SIDE-4623
S3: MSK12C02; Switch (MSK12C02)
U1: USBLC6-2SC6; SOT-23-6
U2: ESP-PSRAM32; SO-8
U3: W25Q128JVSIQ; SOIC-8
U4: RP2040; QFN 56
U5: NCP1117 3.3; SOT-223
Y1: 12 MHz; Crystal (3225)

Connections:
+3V3: C2.2, C7.1, C10.1, C11.1, C12.1, C13.1, C14.1, C15.1, C16.1, C17.1, C19.1, C20.1, C23.1, J1.1, J3.P4 (VDD), R18.2, U2.8 (VCC), U3.8 (VCC), U4.1 (IOVDD), U4.10 (IOVDD), U4.22 (IOVDD), U4.33 (IOVDD), U4.42 (IOVDD), U4.43 (ADC_AVDD), U4.44 (VREG_IN), U4.48 (USB_VDD), U4.49 (IOVDD), U5.2 (VO)
/Audio Out/L: C3.1, J4.T, R5.1
/Audio Out/R: C5.1, J4.R, R9.1
/GPIO2: J3.P5 (CLK), U4.4 (GPIO2)
/GPIO3: J3.P3 (CMD), U4.5 (GPIO3)
/GPIO4: J3.P7 (DAT0), U4.6 (GPIO4)
/GPIO5: J3.P2 (CD/DAT3), U4.7 (GPIO5)
/GPIO6: RN1.4 (R4.1), U4.8 (GPIO6)
/GPIO7: RN1.3 (R3.1), U4.9 (GPIO7)
/GPIO8: RN1.2 (R2.1), U4.11 (GPIO8)
/GPIO9: RN1.1 (R1.1), U4.12 (GPIO9)
/GPIO10: RN2.4 (R4.1), U4.13 (GPIO10)
/GPIO11: RN2.3 (R3.1), U4.14 (GPIO11)
/GPIO12: RN2.2 (R2.1), U4.15 (GPIO12)
/GPIO13: RN2.1 (R1.1), U4.16 (GPIO13)
/GPIO18: U2.1 (~CE), U4.29 (GPIO18)
/GPIO19: U2.6 (SCLK), U4.30 (GPIO19)
/GPIO20: U2.5 (SI/SIO), U4.31 (GPIO20)
/GPIO21: JP1.2 (B), U4.32 (GPIO21)
/GPIO25: R14.2, U4.37 (GPIO25)
/GPIO26: R8.2, U4.38 (GPIO26_ADC0)
/GPIO27: R4.2, U4.39 (GPIO27_ADC1)
/GPIO28: R6.2, R7.2, U4.40 (GPIO28_ADC2)
/PW_D+: R10.1, U1.6 (I/O1)
/PW_D-: R12.1, U1.4 (I/O2)
/RP2040/QSPI_SCLK: U3.6 (CLK), U4.52 (QSPI_SCLK)
/RP2040/QSPI_SD0: U3.5 (DI(IO0)), U4.53 (QSPI_SD0)
/RP2040/QSPI_SD1: U3.2 (DO(IO1)), U4.55 (QSPI_SD1)
/RP2040/QSPI_SD2: U3.3 (IO2), U4.54 (QSPI_SD2)
/RP2040/QSPI_SD3: U3.7 (IO3), U4.51 (QSPI_SD3)
/RP2040/QSPI_SS: R11.1, U3.1 (~CS), U4.56 (QSPI_SS)
/RP2040/XIN: C22.1, U4.20 (XIN), Y1.1
/RP2040/XOUT: R13.1, U4.21 (XOUT)
/RUN: S1.1, U4.26 (RUN)
GND: C1.2, C2.1, C4.2, C6.2, C7.2, C8.2, C9.2, C10.2, C11.2, C12.2, C13.2, C14.2, C15.2, C16.2, C17.2, C18.2, C19.2, C20.2, C21.2, C22.2, C23.2, C24.2, C25.2, J1.2, J2.4 (GND), J3.G1 (GND_1), J3.G2 (GND_2), J3.G3 (GND_3), J3.P6 (VSS), J4.S, J5.1 (GND), J5.12 (GND), J6.2 (G_D2), J6.5 (G_D1), J6.8 (G_D0), J6.11 (G_CLK), J6.17 (G_DDC/CEC), J6.20 (SHIELD1), J6.21 (SHIELD2), J6.22 (SHIELD3), J6.23 (SHIELD4), LD1.1 (K), LD2.1 (K), R3.2, R5.2, R9.2, R15.1, R16.1, R17.2, S1.2, S2.2, U1.2 (GND), U2.4 (VSS), U3.4 (GND), U4.19 (TESTEN), U4.57 (GND), U5.1 (GND), Y1.2, Y1.4
unnamed: C3.2, C4.1, R4.1, R6.1
unnamed: C5.2, C6.1, R7.1, R8.1
unnamed: C21.1, R13.2, Y1.3
unnamed: J2.3 (D+), R1.2
unnamed: J2.2 (D-), R2.2
unnamed: J2.5 (Shield), R3.1
unnamed: J5.4 (CC1), R15.2
unnamed: J5.10 (CC2), R16.2
unnamed: J5.5 (DN2), J5.7 (DN1)
unnamed: J5.6 (DP1), J5.8 (DP2)
unnamed: J5.13 (SHIELD), R17.1
unnamed: J6.12 (CLKN), RN1.5 (R4.2)
unnamed: J6.10 (CLKP), RN1.6 (R3.2)
unnamed: J6.9 (D0N), RN1.7 (R2.2)
unnamed: J6.7 (D0P), RN1.8 (R1.2)
unnamed: J6.6 (D1N), RN2.5 (R4.2)
unnamed: J6.4 (D1P), RN2.6 (R3.2)
unnamed: J6.3 (D2N), RN2.7 (R2.2)
unnamed: J6.1 (D2P), RN2.8 (R1.2)
unnamed: JP1.1 (A), U2.2 (SO/SIO)
unnamed: LD1.2 (A), R14.1
unnamed: LD2.2 (A), R18.1
unnamed: R1.1, U1.1 (I/O1)
unnamed: R2.1, U1.3 (I/O2)
unnamed: R11.2, S2.1
unnamed: J5.2 (VBUS), J5.11 (VBUS), S3.2 (B)
unnamed: R12.2, U4.46 (USB_DM)
unnamed: R10.2, U4.47 (USB_DP)
unnamed: C8.1, C9.1, C18.1, U4.23 (DVDD), U4.45 (VREG_VOUT), U4.50 (DVDD)
VBUS: C1.1, C24.1, C25.1, J1.3, J2.1 (VBUS), J6.18 (+5V), S3.3 (A), U1.5 (VBUS), U5.3 (VI)

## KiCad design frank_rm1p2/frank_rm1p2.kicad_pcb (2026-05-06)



Board: 4 copper layers, 64.7 x 86.0 mm, 173 parts (2 on the bottom side), 138 nets.

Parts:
C1, C5, C6, C9, C10, C47, C49, C50, C51, C52, C53, C56, C57: 10u; Capacitor (0603)
C2, C3, C4, C7, C8, C11, C13, C14, C15, C16, C17, C18, C19, C20, C21, C25, C26, C27, C28, C29, C30, C31, C32, C33, C34, C35, C36, C39, C45, C48, C58: 100n; Capacitor (0402)
C12, C22, C23, C24: 4.7u; Capacitor (0603)
C37, C38, C42, C43, C46: 1u; Capacitor (0603)
C40, C41: 15p; Capacitor (0402)
C44: 47u; Capacitor (0603)
C54, C55: 47n; Capacitor (0402)
D1, D3: 3V3; Diode (SOD-323)
D2: 1N4148; Diode (SOD-323)
D4: 1N5819WS; Diode (SOD-323)
H1, H2, H3, H4: MountingHole; Mounting Hole (2.7mm)
J1: PWR; Pin Header (1x03)
J2, J10: D-SUB 9 Male; D-SUB (9 pin, male, top mount)
J3, J13: USB4215-03-A; USB Type C
J4: 0475710001; MicroSD (SMD, short)
J5: 104031-0811; MicroSD (SMD, long)
J6: PAM L; Connector Female 1.25 JST 2P
J7: PAM R; Connector Female 1.25 JST 2P
J8, J9: PJ-320D; Jack (3.5mm, PJ-320D)
J11: SS-52100-004; USB Type A (stacked)
J12: DC3RX19JA2; HDMI (female)
J14: Pin Header 1x08; Connector Female 1.25 JST 8P
JP1: Main Jumpers; SW_DS05-127-2-03BK-SMT-TR
JP2: Mouse (DATA); Jumper (solder)
JP3: Mouse (CLK); Jumper (solder)
L1: 3.3u; Inductor (0806)
LD1: Power; LED (0402)
LD2, LD3: Blue; LED (0402)
Q1, Q2: BC850; SOT-23
R1, R2, R3, R4, R11, R13, R14, R21, R32, R33, R41, R42, R43, R44, R45, R46, R48, R50, R53, R56, R57: 10K; Resistor (0402)
R5, R12, R16, R27, R31, R35, R37, R39, R40, R58, R59: 1K; Resistor (0402)
R6, R9, R22, R25: 5.1K; Resistor (0402)
R7, R8, R17, R18, R19, R20, R23, R24: 22R; Resistor (0402)
R10, R26: 1M; Resistor (0402)
R15: 100R; Resistor (0402)
R28: 33R; Resistor (0402)
R29, R30, R36, R38: 27R; Resistor (0402)
R34: 0R; Resistor (0402)
R47, R52: 20K; Resistor (0402)
R49, R51: 47K; Resistor (0402)
R54, R55, R60, R61: 2K; Resistor (0402)
R62, R63: 470R; Resistor (0402)
RN1, RN2: 270R; Resistor Array (4x0603)
S1: Reset RP2530A; TACT-SIDE-4623
S2: Reset RP2040; TACT-SIDE-4623
S3: MSK12C02; Switch (MSK12C02)
S4: Boot 2350; TACT-SIDE-4623
S5: Boot 2040; Button (SMD, 3x3mm, 1-1)
U1, U4: USBLC6-2SC6; SOT-23-6
U2: 74HC4052D; SOP-16
U3: NCP1117 3.3; SOT-223
U5: RP2350; QFN 60 (RP2350A)
U6: ESP-PSRAM32; SO-8
U7: W25Q128JVS; SOIC-8
U8: W25Q128JVSIQ; SOIC-8
U9: RP2040; QFN 56
U10: PAM8403D; SOP-16
U11: LM358; SO-8
U12: TDA1387T; SO-8
Y1: ASE-12MHz; Crystal (3225, active)
Y2: 12 MHz; Crystal (3225)

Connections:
+1V1: C11.1, C12.1, C13.1, C24.1, L1.1, U5.6 (DVDD), U5.23 (DVDD), U5.39 (DVDD), U5.50 (VREG_FB)
+3V3: C2.2, C3.1, C8.2, C9.1, C14.1, C15.1, C16.1, C17.1, C18.1, C19.1, C20.1, C21.1, C23.1, C25.1, C26.1, C29.1, C30.1, C31.1, C32.1, C33.1, C34.1, C35.1, C36.1, C38.1, C39.1, J1.1, J4.P4 (VDD), J5.4 (VDD), R1.2, R2.2, R3.2, R4.2, R11.1, R12.1, R27.2, R28.1, R32.2, R33.1, U2.16 (VCC), U3.2 (VO), U5.1 (IOVDD), U5.11 (IOVDD), U5.20 (IOVDD), U5.30 (IOVDD), U5.38 (IOVDD), U5.44 (ADC_AVDD), U5.45 (IOVDD), U5.49 (VREG_VIN), U5.53 (USB_OTP_VDD), U5.54 (QSPI_IOVDD), U6.8 (VCC), U7.8 (VCC), U8.8 (VCC), U9.1 (IOVDD), U9.10 (IOVDD), U9.22 (IOVDD), U9.33 (IOVDD), U9.42 (IOVDD), U9.43 (ADC_AVDD), U9.44 (VREG_IN), U9.48 (USB_VDD), U9.49 (IOVDD), Y1.1 (EN), Y1.4 (Vdd)
/AMP_IN_L: C49.1, R44.1, U2.13 (1Z)
/AMP_IN_R: C51.1, R45.1, U2.3 (2Z)
/AUDIOSW: JP1.1, R21.2, U2.10 (S0)
/Audio Out/AMP_OUTL: C50.2, J8.T, R47.2
/Audio Out/AMP_OUTR: C52.2, J8.R, R52.2
/Audio Out/AMP_PAM_OUTL_M: J6.2, U10.3 (-OUTL)
/Audio Out/AMP_PAM_OUTL_P: J6.1, U10.1 (+OUT_L)
/Audio Out/AMP_PAM_OUTR_M: J7.2, U10.14 (-OUT_R)
/Audio Out/AMP_PAM_OUTR_P: J7.1, U10.16 (+OUT_R)
/D+: R29.1, U1.4 (I/O2)
/D-: R30.1, U1.6 (I/O1)
/DAT1: J4.P8 (DAT1), J5.8 (DAT1)
/DAT2: J4.P1 (DAT2), J5.1 (DAT2)
/GPIO0: R1.1, U5.2 (GPIO0), U9.15 (GPIO12)
/GPIO1: R2.1, U5.3 (GPIO1), U9.14 (GPIO11)
/GPIO2: J4.P5 (CLK), J5.5 (CLK), U5.4 (GPIO2)
/GPIO3: J4.P3 (CMD), J5.3 (CMD), U5.5 (GPIO3)
/GPIO4: J4.P7 (DAT0), J5.7 (DAT0), U5.7 (GPIO4)
/GPIO5: J4.P2 (CD/DAT3), J5.2 (DAT3/CD), U5.8 (GPIO5)
/GPIO6: J14.3, RN1.4 (R4.1), U5.9 (GPIO6)
/GPIO7: RN1.3 (R3.1), U5.10 (GPIO7)
/GPIO8: J14.4, RN1.2 (R2.1), U5.12 (GPIO8)
/GPIO9: J14.8, RN1.1 (R1.1), U5.13 (GPIO9)
/GPIO10: J14.5, RN2.4 (R4.1), U5.14 (GPIO10)
/GPIO11: RN2.3 (R3.1), U5.15 (GPIO11)
/GPIO12: J14.6, RN2.2 (R2.1), U5.16 (GPIO12)
/GPIO13: J14.7, RN2.1 (R1.1), U5.17 (GPIO13)
/GPIO14: J2.4, J10.4, JP3.2 (B), R3.1, U5.18 (GPIO14)
/GPIO15: J2.3, J10.3, JP2.2 (B), R4.1, U5.19 (GPIO15)
/GPIO16: D3.1 (K), R16.1, U5.27 (GPIO16)
/GPIO17: D1.1 (K), R5.1, U5.28 (GPIO17)
/GPIO19: R32.1, U5.31 (GPIO19), U6.1 (~CE)
/GPIO22: Q1.3 (C), R12.2, U5.34 (GPIO22)
/GPIO26: R59.2, U5.40 (GPIO26_ADC0), U12.3 (DATA)
/GPIO27: R58.2, U5.41 (GPIO27_ADC1), U12.1 (SCLK)
/GPIO28: R54.1, R55.1, U5.42 (GPIO28_ADC2), U12.2 (LRCK)
/MONO_L: C43.1, JP1.3, R44.2
/MONO_R: C46.1, JP1.4, R45.2
/MS_CLK: JP3.1 (A), U9.18 (GPIO15)
/MS_DATA: JP2.1 (A), U9.17 (GPIO14)
/PWM_OUT_L: R57.2, R61.1, U2.12 (1Y0)
/PWM_OUT_R: R56.2, R60.1, U2.1 (2Y0)
/RP2_D+: R36.1, U4.4 (I/O2)
/RP2_D-: R38.1, U4.6 (I/O1)
/RP2_GPIO2: R17.1, U9.4 (GPIO2)
/RP2_GPIO3: R19.1, U9.5 (GPIO3)
/RP2_GPIO4: R18.1, U9.6 (GPIO4)
/RP2_GPIO5: R20.1, U9.7 (GPIO5)
/RP2_RUN: S2.1, U9.26 (RUN)
/RP2040/GPIO25: R40.2, U9.37 (GPIO25)
/RP2040/QSPI_SCLK: U8.6 (CLK), U9.52 (QSPI_SCLK)
/RP2040/QSPI_SD0: U8.5 (DI(IO0)), U9.53 (QSPI_SD0)
/RP2040/QSPI_SD1: U8.2 (DO(IO1)), U9.55 (QSPI_SD1)
/RP2040/QSPI_SD2: U8.3 (IO2), U9.54 (QSPI_SD2)
/RP2040/QSPI_SD3: U8.7 (IO3), U9.51 (QSPI_SD3)
/RP2040/QSPI_SS: R37.1, U8.1 (~CS), U9.56 (QSPI_SS)
/RP2040/XIN: C41.1, U9.20 (XIN), Y2.1
/RP2040/XOUT: R39.1, U9.21 (XOUT)
/RP2350A/FLASH_SS: R33.2, R34.2, U7.1 (~CS)
/RP2350A/QSPI_SCLK: U5.56 (QSPI_SCLK), U6.6 (SCLK), U7.6 (CLK)
/RP2350A/QSPI_SD0: U5.57 (QSPI_SD0), U6.5 (SI/SIO), U7.5 (DI(IO0))
/RP2350A/QSPI_SD1: U5.59 (QSPI_SD1), U6.2 (SO/SIO), U7.2 (DO(IO1))
/RP2350A/QSPI_SD2: U5.58 (QSPI_SD2), U6.3 (SIO2), U7.3 (IO2)
/RP2350A/QSPI_SD3: U5.55 (QSPI_SD3), U6.7 (SIO3), U7.7 (IO3)
/RP2350A/QSPI_SS: R31.1, R34.1, U5.60 (QSPI_SS)
/RP2350A/VREG_AVDD: C22.1, R28.2, U5.46 (VREG_AVDD)
/RP2350A/VREG_LX: L1.2, U5.48 (VREG_LX)
/RP2350A/XIN: U5.21 (XIN), Y1.3 (OUT)
/RP2350A/~USB_BOOT: R31.2, S4.2
/RUN: S1.1, U5.26 (RUN)
/SHND: JP1.2, R42.2, U10.12 (SHND)
/TDA_L: R63.2, U2.14 (1Y1), U12.6 (A_LEFT)
/TDA_R: R62.1, U2.5 (2Y1), U12.8 (A_RIGHT)
GND: C1.2, C2.1, C3.2, C5.2, C6.2, C7.2, C8.1, C9.2, C10.2, C11.2, C12.2, C13.2, C14.2, C15.2, C16.2, C17.2, C18.2, C19.2, C20.2, C21.2, C22.2, C23.2, C24.2, C25.2, C26.2, C27.2, C28.2, C29.2, C30.2, C31.2, C32.2, C33.2, C34.2, C35.2, C36.2, C37.2, C38.2, C39.2, C40.2, C41.2, C42.2, C44.2, C45.2, C47.1, C48.1, C53.1, C54.2, C55.2, C56.2, C57.2, C58.2, D1.2 (A), D3.2 (A), J1.2, J2.8, J3.1 (GND), J3.12 (GND), J4.G1 (GND_1), J4.G2 (GND_2), J4.G3 (GND_3), J4.P6 (VSS), J5.6 (VSS), J8.S, J9.S, J10.8, J11.4 (GND1), J11.8 (GND2), J11.9 (Shield), J12.2 (G_D2), J12.5 (G_D1), J12.8 (G_D0), J12.11 (G_CLK), J12.17 (G_DDC/CEC), J12.20 (SHIELD1), J12.21 (SHIELD2), J12.22 (SHIELD3), J12.23 (SHIELD4), J13.1 (GND), J13.12 (GND), J14.2, JP1.5, LD1.1 (K), LD2.1 (K), LD3.1 (K), Q1.2 (E), Q2.2 (E), R6.1, R9.1, R10.2, R15.2, R21.1, R22.1, R25.1, R26.2, R47.1, R52.1, R53.1, R60.2, R61.2, R62.2, R63.1, S1.2, S2.2, S4.1, S5.2, U1.2 (GND), U2.2 (2Y2), U2.4 (2Y3), U2.6 (~E), U2.7 (VEE), U2.8 (GND), U2.9 (S1), U2.11 (1Y3), U2.15 (1Y2), U3.1 (GND), U4.2 (GND), U5.47 (VREG_PGND), U5.61 (GND), U6.4 (VSS), U7.4 (GND), U8.4 (GND), U9.19 (TESTEN), U9.57 (GND), U10.2 (PGND), U10.11 (GND), U10.15 (PGND), U11.4 (V-), U12.4 (AGND), Y1.2 (GND), Y2.2, Y2.4
GPIO25: R35.2, U5.37 (GPIO25)
unnamed: C4.1, J9.T, R15.1
unnamed: C4.2, R14.1
unnamed: C40.1, R39.2, Y2.3
unnamed: C43.2, R41.2
unnamed: C46.2, R43.2
unnamed: C49.2, R48.2
unnamed: C50.1, R49.1, U11.7
unnamed: C51.2, R50.2
unnamed: C52.1, R51.1, U11.1
unnamed: C54.1, R54.2, R56.1, R59.1
unnamed: C55.1, R55.2, R57.1, R58.1
unnamed: D2.2 (A), Q2.3 (C), R11.2, R13.1
unnamed: D2.1 (K), Q2.1 (B), R14.2
unnamed: C7.1, D4.1 (K), J12.18 (+5V)
unnamed: J2.2, R5.2
unnamed: J3.4 (CC1), R6.2
unnamed: J3.10 (CC2), R9.2
unnamed: J3.5 (DN2), J3.7 (DN1), R7.2
unnamed: J3.6 (DP1), J3.8 (DP2), R8.2
unnamed: J3.13 (SHIELD), R10.1
unnamed: J10.2, R16.2
unnamed: J11.3 (D1+), R17.2
unnamed: J11.2 (D1-), R19.2
unnamed: J11.7 (D2+), R18.2
unnamed: J11.6 (D2-), R20.2
unnamed: J12.12 (CLKN), RN1.5 (R4.2)
unnamed: J12.10 (CLKP), RN1.6 (R3.2)
unnamed: J12.9 (D0N), RN1.7 (R2.2)
unnamed: J12.7 (D0P), RN1.8 (R1.2)
unnamed: J12.6 (D1N), RN2.5 (R4.2)
unnamed: J12.4 (D1P), RN2.6 (R3.2)
unnamed: J12.3 (D2N), RN2.7 (R2.2)
unnamed: J12.1 (D2P), RN2.8 (R1.2)
unnamed: J13.4 (CC1), R22.2
unnamed: J13.10 (CC2), R25.2
unnamed: J13.5 (DN2), J13.7 (DN1), R23.2
unnamed: J13.6 (DP1), J13.8 (DP2), R24.2
unnamed: J13.13 (SHIELD), R26.1
unnamed: LD1.2 (A), R27.1
unnamed: LD2.2 (A), R35.1
unnamed: LD3.2 (A), R40.1
unnamed: Q1.1 (B), R13.2
unnamed: R7.1, U1.1 (I/O1)
unnamed: R8.1, U1.3 (I/O2)
unnamed: R23.1, U4.1 (I/O1)
unnamed: R24.1, U4.3 (I/O2)
unnamed: R37.2, S5.1
unnamed: J13.2 (VBUS), J13.11 (VBUS), S3.2 (B)
unnamed: R30.2, U5.51 (USB_DM)
unnamed: R29.2, U5.52 (USB_DP)
unnamed: R38.2, U9.46 (USB_DM)
unnamed: R36.2, U9.47 (USB_DP)
unnamed: C27.1, C28.1, C37.1, U9.23 (DVDD), U9.45 (VREG_VOUT), U9.50 (DVDD)
unnamed: R41.1, U10.7 (INL)
unnamed: R43.1, U10.10 (INR)
unnamed: C45.1, U10.8 (VREF)
unnamed: C53.2, R46.1, R53.2, U11.3 (+), U11.5 (+)
unnamed: R50.1, R51.2, U11.2 (-)
unnamed: R48.1, R49.2, U11.6 (-)
unnamed: C56.1, U12.7 (FLT)
VBUS: C1.1, C5.1, C6.1, C10.1, C42.1, C44.1, C47.2, C48.2, C57.1, C58.1, D4.2 (A), J1.3, J2.6, J3.2 (VBUS), J3.11 (VBUS), J10.6, J11.1 (VBUS1), J11.5 (VBUS2), J14.1, JP1.6, R42.1, R46.2, S3.3 (A), U1.5 (VBUS), U3.3 (VI), U4.5 (VBUS), U10.4 (PVDD), U10.5 (MUTE), U10.6 (VDD), U10.13 (PVDD), U11.8 (V+), U12.5 (VA)

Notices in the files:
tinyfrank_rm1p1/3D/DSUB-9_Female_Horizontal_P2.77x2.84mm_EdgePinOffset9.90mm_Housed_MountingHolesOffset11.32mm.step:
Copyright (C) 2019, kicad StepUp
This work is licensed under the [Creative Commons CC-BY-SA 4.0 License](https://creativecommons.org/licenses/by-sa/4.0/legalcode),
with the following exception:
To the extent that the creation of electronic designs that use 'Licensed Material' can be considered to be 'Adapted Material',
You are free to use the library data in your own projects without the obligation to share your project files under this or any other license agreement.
